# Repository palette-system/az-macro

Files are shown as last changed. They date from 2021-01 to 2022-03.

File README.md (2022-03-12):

# AZ-Macro

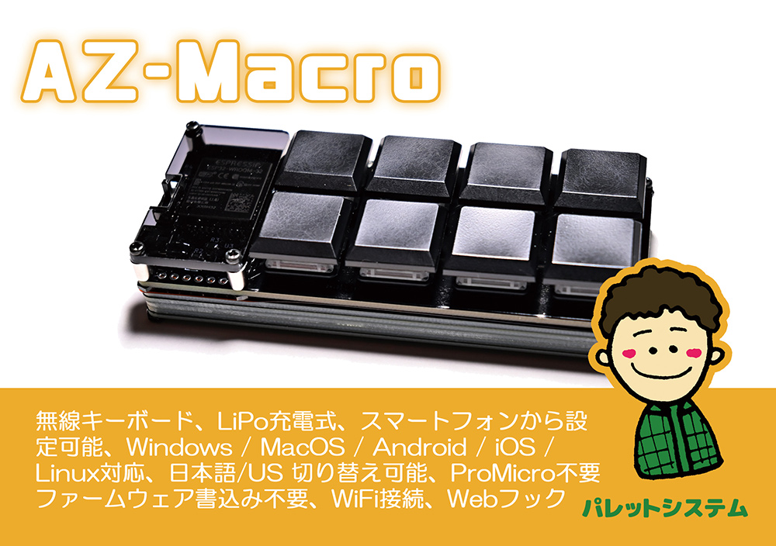
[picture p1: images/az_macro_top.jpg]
ボード設定


## メディア
<br>
【twitter】 山本アヒル 先生<br>
ツイッターPR<br>
https://twitter.com/AHIRU_7/status/1379755170599346183
<br><br>

<br>
【動画】Daihuku Keyboard 様<br>
組み立て、ZOOM、お絵かきソフト、google apps scriptとの連携<br>
https://www.youtube.com/watch?v=hTy6ZXIW0Vs
<br><br>

【動画＆ブログ】さきチャンネル 様<br>
組み立て、ショートカット設定、おみくじ、IFTTTとの連携<br>
動画： https://www.youtube.com/watch?v=Y7fYM1RlOd8&t=23s
<br>
ブログ： https://sakiot.com/iot-keyboard-az-macro/
<br><br>

【記事】AKIBA PC Hotline 様<br>
https://akiba-pc.watch.impress.co.jp/docs/news/news/1336355.html
<br>
https://akiba-pc.watch.impress.co.jp/docs/news/news/1306228.html
<br>

【記事】Yahooニュース 様<br>
https://news.yahoo.co.jp/articles/7b6afe8f1dbb792dc17484e3a8a71e1b7dceda1f
<br><br>

【ブログ】オノフ 様<br>
組み立て、設定方法<br>
https://onofuu.com/post-122/
<br><br>

【ブログ】道具眼日誌 様<br>
パーツ選び、組み立て、設定方法<br>
https://do-gugan.com/~furuta/archives/2021/05/az-macro_1.html
<br>
トラックボールの組み立て、設定方法<br>
https://do-gugan.com/~furuta/archives/2021/07/az-macro_trackball.html
<br><br>

【ツイート　イラスト】かわなえ 様<br>
https://twitter.com/kawai_nae/status/1494585308452585475
<br><br>

## ドキュメント
  
  ※キット購入の方も、組み立て済みの方もまずは「ファームウェアの初期セットアップ」を行って下さい。
  
[ファームウェアの初期セットアップ](/docs/firmware_write/)  
<br><br>

- [基本操作マニュアル](/docs/use_manual/)
- [作成マニュアル](/docs/az-macro-create-manual.pdf)
- [設定マニュアル](/docs/az-macro-setting-manual.pdf)
- [WEBHookマニュアル](/docs/webhook/)
- [ファームウェアの更新手順](/docs/firmware_update/)
- [入力できるキーの一覧](/docs/key_list/)
- [トラックボールユニットの設定](/docs/track_unit/)
<br><br>

## ファームウェア

- [ソース](/firmware/)
- [binファイル](/firmware/bin/azmacro/)
<br><br>

## ハードウェアデータ

- [プレートデータ](/plate/)
<br><br>

## リンク

- [パレットシステム通販サイト](https://palette-system.booth.pm/)

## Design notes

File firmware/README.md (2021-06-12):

# AZ-Macro ファームウェア
AZ-Macroで使用しているファームウェアソースです。<br>
こちらのソースは個人で利用する場合には自由にご利用いただいて大丈夫です。<br>
二次配布については非営利であれば著作権表示をして頂ければご利用して頂いて大丈夫です。<br>

<br><br>

ライセンス：　CC BY-NC-SA 4.0

<br><br>

## 対応商品

- AZ-Macro
- AZ-Macro (option)踏みキー

## 開発環境

- Arduino 1.8.13
- esp32 1.0.4
- ESP OTA 0.0.3
- NimBLE-Arduino 1.0.2
- ArduinoJson 6.17.2

## 書込み時のボード設定

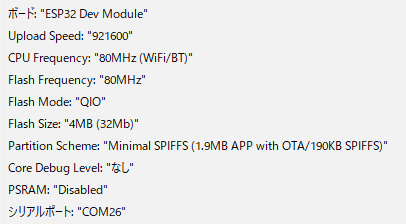
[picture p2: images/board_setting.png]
ボード設定


## AZ-66JP で SPIFFS 領域を16MBにする

[16MBフラッシュのESP32-WROVERでSPIFFSを最大限使えるようにする設定方法](https://kohacraft.com/archives/202012051149.html)

## こちらのツールを使用させて頂いています

- [PROGMEM作蔵さん](https://hello-world.blog.ss-blog.jp/2016-10-16)

## こちらのライブラリを使用させて頂いています

- [NimBLE-Arduino](https://github.com/h2zero/NimBLE-Arduino)
- [qrcode](https://github.com/ricmoo/qrcode/)

※ NimBLEはZIPファイルでライブラリ追加

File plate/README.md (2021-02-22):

# プレートデータ
AZ-Macroで使用している各プレートのDXFファイル、SVGファイルです。<br>
こちらのデータは個人で利用する分には自由にご利用いただいて大丈夫です。<br>
商用利用する場合も著作権表記して頂ければ自由にご利用いただいて大丈夫です。<br>

<br><br>

ライセンス：　CC BY-SA 4.0

<br><br>

## 保護プレート
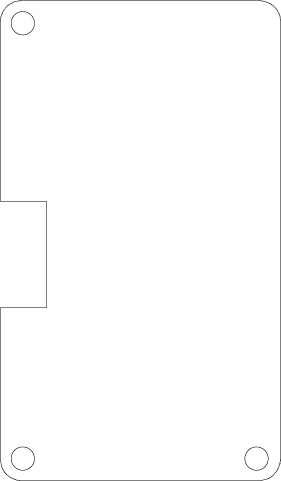
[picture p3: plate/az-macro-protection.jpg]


### Download
- [SVG](/plate/az-macro-protection.svg)
- [DXF](/plate/az-macro-protection.dxf)

<br><br>

## ミドルプレート
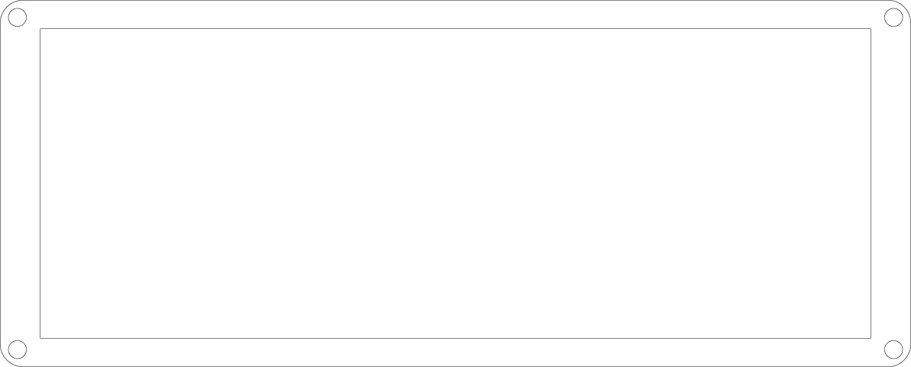
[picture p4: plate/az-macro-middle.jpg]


### Download
- [SVG](/plate/az-macro-middle.svg)
- [DXF](/plate/az-macro-middle.dxf)

<br><br>

## ボトムプレート
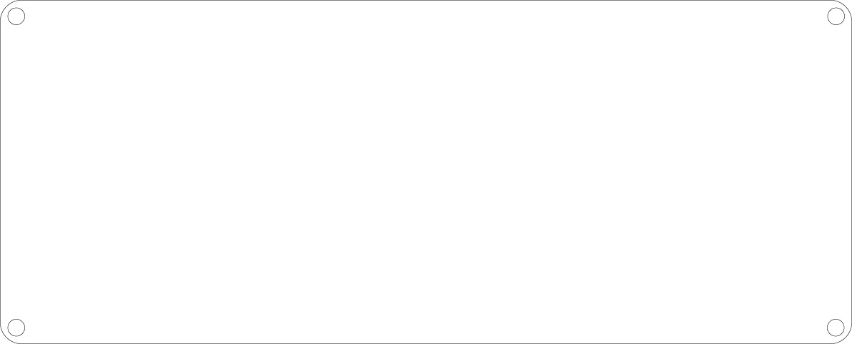
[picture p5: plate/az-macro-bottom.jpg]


### Download
- [SVG](/plate/az-macro-bottom.svg)
- [DXF](/plate/az-macro-bottom.dxf)

<br><br>

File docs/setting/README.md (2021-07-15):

# 設定方法

<br>

## 設定画面の入り方

[AZ-66JP](/docs/setting/az66jp/)

<br><br>

## マニュアル

[設定マニュアル(PDF)](/docs/az-macro-setting-manual.pdf)

<br><br>

## キーの設定

[暗記ボタンの設定](/docs/setting/key/ankey/)

[打鍵ボタンの設定](/docs/setting/key/daken/)

[カラーLEDボタンの設定](/docs/setting/key/led/)

<br><br>

## ユニットの設定

[液晶ユニットの設定](/docs/setting/unit/tft/)

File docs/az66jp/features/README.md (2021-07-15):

# AZ-66JP 製品特徴

<br>
<br>

## ■ 暗記ボタン機能
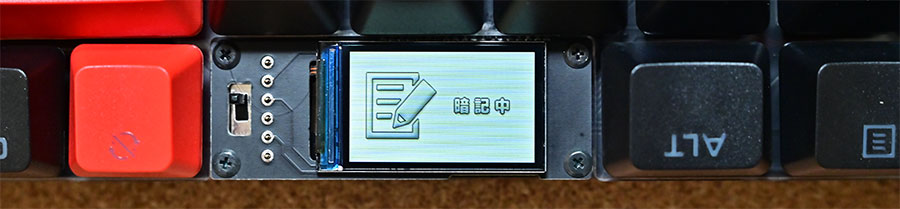
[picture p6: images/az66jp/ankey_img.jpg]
ankey_img
<br>
キーの推した順番、離した順番を暗記してボタンに覚えさせる機能を付けました。<br>
同じ入力を繰り返し入力したい場合、使用頻度が多ければ今までツールやショートカットキーを登録すれば実現できたのですが、使用頻度が少ない物は登録するのがいちいち面倒くさい場合が多くそのまま繰り返し入力している事が多かったのでこの機能を作りました。<br>
「暗記ボタン」を使う事でツールで設定をせず、今欲しいショートカットをスグに作る事ができます。<br>
使い方としては「暗記ボタン」として登録してあるキーを長押しするとキーボードが暗記モードになります。暗記モード中に入力したキー情報(暗記モード中も普通にキー入力されます)を最大1000回までキーを押した、離したの情報を暗記できます。<br>
暗記させたいキー入力が終わったらもう一度「暗記ボタン」を押すと暗記終了になります。暗記データがある状態で「暗記ボタン」を押すと暗記してある入力が自動で入力されます。<br>
「暗記ボタン」はキーマップの設定からいくつも登録できてESP32の容量が許す限り登録可能です。<br>
暗記したデータはESP32内に保存しますので、キーボードを再起動しても暗記した内容は保持されます。<br>
<br>
　※ 暗記するのはどのキーを押したかという情報なので、該当のキーのキーマップを書き換えると入力される内容も変わります<br>
　※ CtrlやAlt、カーソルキーやエンターキーTabキーなど登録できる全てのキーの暗記が可能です。<br>
　※ 「Ctrl＋C」→「Ctrl＋V」→「Ctrl＋V」→「Ctrl＋V」を暗記して選択したテキストを複数回張り付けるなども可能です<br>
<br>
暗記ボタンの使い方はこちら ： [リンク](/docs/az66jp/ankey/)

<br>
<br>

## ■ 打鍵ヒートマップ機能
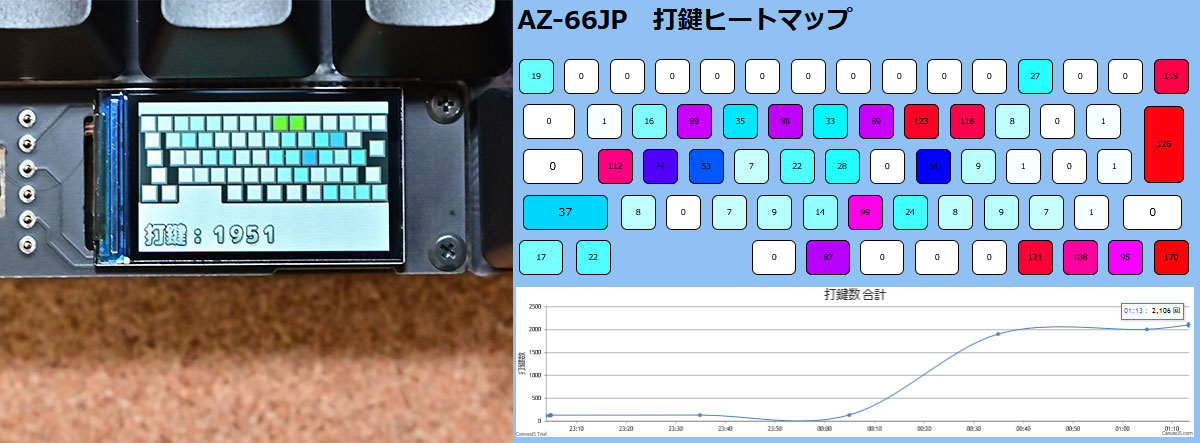
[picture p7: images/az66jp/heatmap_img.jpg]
heatmap_img
<br>
キーボードを起動してから現在までのトータル打鍵数とキーごとの打鍵数を30分おきにデータを残す事で、今どれくらいのペースでキーボードを入力したかを分かるようにしました。<br>
打鍵数は本体の液晶で確認できるだけでなく、液晶に表示されたQRコードを読み込めばスマホやPCからも打鍵ヒートマップを見れます。<br>
今の所は起動してからどれくらい打鍵したかしか見れませんが、ESP32本体に過去の打鍵数を保存できる容量はあるので今後のファームウェアアップデートで過去の分もさかのぼって確認できるようにする予定です。<br>

<br>
<br>

## ■ アプリのインストール無し、専門知識無しにキーマップを変更できる
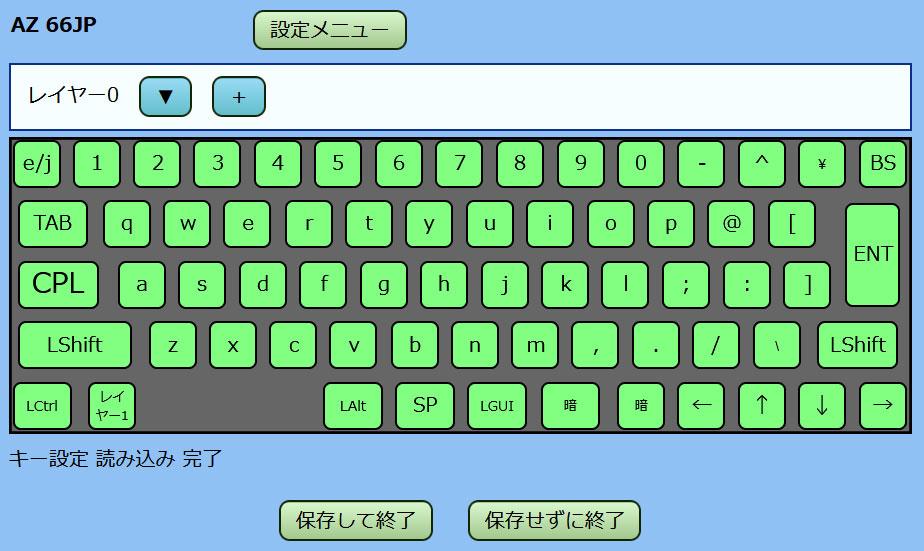
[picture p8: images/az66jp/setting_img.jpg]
setting_img
<br>
AZ-Macro同様のファームウェアを採用し、スマホやPCからWifiに接続するだけで設定画面が開けます。<br>
専門知識が無くても設定画面を見ればすぐに操作できるようになっていて、自作キーボードを初めて触る方でも簡単にキーマップの編集が行えます。<br>
レイヤー機能も搭載していて、Fnボタンのように押したまま他のボタンを押した時の動作を登録できます。レイヤー数に制限は無く複数のレイヤーが作成可能です。<br>

<br>
<br>

## ■ 初めての人も使いやすい日本語配列
66キーの60％サイズなので十字キーが横並びになっていたりスペースキーを狭くしていますが、普段使っているキーボードに近い日本語配列を採用しました。<br>
デフォルトのキーマップでは左下のCtrlの隣がレイヤー切り替えボタンとなっていて、そのボタンを押したまま最上列のキーを押すとF1～F12のファンクションキーも押せます。<br>
全てのキーに割り当てられるキーは設定ページから好きなように変更できます。<br>

<br>
<br>

## ■ 対応OS
WindowsやMacでの使用はもちろんの事、Android、iPhone、iPadなどのモバイル端末との接続もできるようになっています。<br>
特にiOSへ問題なく接続できる製品は少ないようでライブラリの修正が大変でしたが問題なく接続できるようになっています。<br>
また日本語キーボード←→USキーボードの変更も設定画面から変更できるようになっているので、PCやスマホの設定に合わせて変更して下さい。<br>

<br>
<br>

## ■ 打鍵音、打鍵感
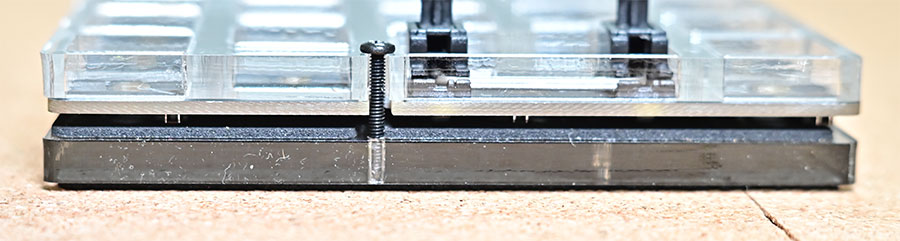
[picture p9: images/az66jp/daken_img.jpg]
daken_img
<br>
打鍵音はメカニカルスイッチを使用する上で重要な要素と考えており音についてはかなりこだわりました。<br>
打鍵時のPCBのカチャカチャ音を失くすためトッププレートは隙間の少ない専用の5mmアクリルプレートを採用。<br>
構造はトッププレートとボトムプレートを支柱でとめるのが主流ですが、そうするとボトムプレートに振動が伝わりボトムプレートがカチャカチャ鳴ってしまうので、あえて繋げず間に滑り止め用のスポンジでPCBとトッププレートを支える構造にしました。<br>
スポンジが振動を吸収してくれるので長時間の作業での指への負担を軽減してくれるのと、スポンジ内に空気が入っているため静音材の役割も果たしてくれて余計な音が鳴るのをを減らしてくれます。<br>
キーボードの裏にもこだわり、ゴム足を使用せず裏にもスポンジを採用しました。<br>
ゴム足を付けると机とボトムプレートの間に空いた空間のせいでボトムプレートから響き音が出てしまうので、点ではなく面でキーボードを支える事で余計な音が鳴るのを減らしてくれます。<br>
打鍵音には好みがあるので一概に良し悪しを決める事はできないのですが、テスターでテストしている打鍵音に近い状態でキー入力できるようこだわりましたので是非試してみて下さい。<br>

<br>
<br>

## ■ ESP32
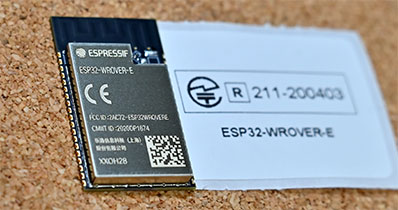
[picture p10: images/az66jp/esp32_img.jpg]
esp32_img
<br>
マイコンはESP32-WROVER-E(16MB)を採用しました。このマイコンは消費電力も大きいし、本体サイズも大きくPCBへの配置もしにくいため自作キーボードに向いていません。<br>
あえてESP32を採用したのは、現在キーボードで主流であるAVRマイコンに比べメモリも大きく多機能(Wifi、Bluetooth、タッチセンサ、DACなど)であるため今までのキーボードでは実装できなかったいろいろな機能が付ける事ができると考えました。<br>
AZ-66JPでは他のキーボードに無い機能をお届けいたします。<br>

<br>
<br>

## ■ カラー液晶
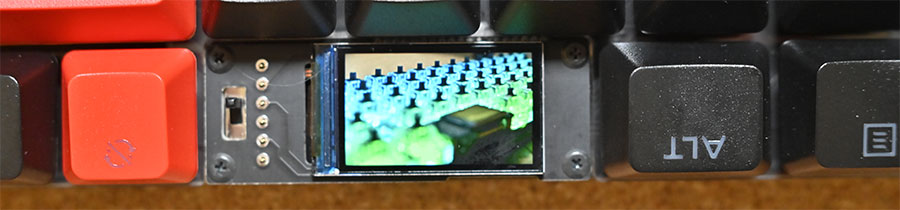
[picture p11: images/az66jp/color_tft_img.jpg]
<br>
キーボードに機能を追加していく上で操作情報を画面表示するために液晶が必須になり採用しました。<br>
ESP32の大容量があるのでカラーで画像表示をしたかったのと、空いたスペースに収まる最大のサイズにしたく240×135というサイズの液晶を採用しました。<br>
液晶の表示ライブラリが動作が遅い物が多く、表示を切り替えている間にキー入力がされるとキーが入力されない事があったので、ライブラリの通信部分の高速化や、画面の一部分だけの書換えで通信量を減らすなどしてキー入力に影響が出ないよう調整するのに苦労しました。<br>
部屋を暗くすると液晶が眩しくなってしまうため、液晶裏にボリュームを付けて液晶の明るさを調整できるようになっています。<br>
そのままボリュームを付けるとPCB外に飛び出た部分がGH60サイズのケースにあたってしまい入らなくなるので、PCBを少し凹ませてその部分でボリュームを調節できるようになっています。<br>
設定ページからJPEG、PNGの画像ファイルを設定すれば待ち受けの画像を変更できます。<br>

<br>
<br>

## ■ GH60のケース互換
GH60互換のケースは種類が多く沢山のデザインや素材があるため、初めて自作キーボードを手にする方が選びやすいケースだと思います。<br>
なのでPCBはGH60互換となるよう設計しました。アルミのケースも2種類ほど試しましたが問題なくBluetooth接続できました。<br>
ESP32の実装位置も、最初は裏面に設置していたのですがそうするとケースによってぶつかってしまう事があったのでGH60ケース互換にするためにESP32の実装は表面になっています。<br>
<br>
　※ 細かい所で差があったり表面実装しているパーツに干渉する可能性があるので互換ケースに入れる際は自己責任でお願いいたします<br>

<br>
<br>

## ■ 電源の接続
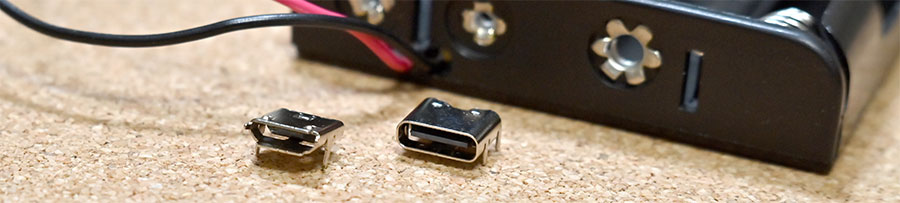
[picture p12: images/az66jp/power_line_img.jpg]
<br>
基本電源はモバイルバッテリーの利用を想定していますが、1種類のコネクタだけではなく選べるようにしました。<br>
コネクタをMicroB、Type-C、銅線から選ぶ事ができます。PCはもちろんUSB充電用のアダプタからUSBコネクタへの給電や、乾電池だと単３を３～４本で動作する事ができます。<br>
キットで購入するとコネクタははんだ付けされていない状態ですので、銅線をはんだ付けしてドーターボードから給電する事も可能です。<br>
またUSBコネクタから電源スイッチの間にスルーホールの穴があけてあり、知識のある方はここにリチウムバッテリーの充電モジュールなどを拡張したりの改造ができるようになっています。(ここの拡張に関しては自己責任でお願いいたします)<br>
<br>
　※ MicroBコネクタのモバイルバッテリーを変換コネクタを使用してType-Cに変換してから給電するとバッテリーを認識しない場合があります。その場合AZ-66JPの電源スイッチをONのままType-Cのコネクタをゆっくりさすと認識します。<br>
　※ 給電電圧は3.5～8Vの範囲内でお願いします。8V以上の電圧を流すとキーボードが壊れます。<br>
　※ 給電電流は500mAほど必要でCR2012などのボタン電池では電流が足りず起動しません。<br>

<br>
<br>

## ■ バッテリー内蔵ボトムプレート
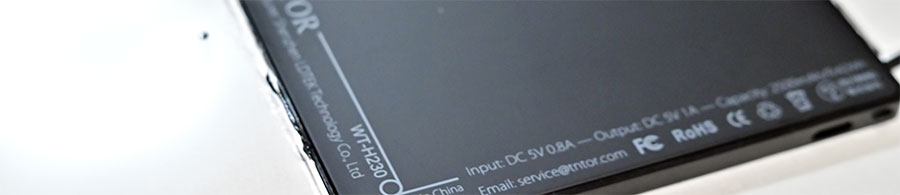
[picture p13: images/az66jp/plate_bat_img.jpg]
plate_bat_img
<br>
専用のバッテリー内蔵のプレートは必要だと思いオプションとして作成しました。<br>
まずシンプルで安全というのが最優先にあったのでバッテリーユニットはモバイルバッテリーを採用しました。<br>
次に可能な限り薄くしたかったのでモバイルバッテリーの中で薄くて手に入りやすい物を採用し、それに合うサイズのボトムプレートを作成しました。<br>
重みもあるのでキー入力時の安定感につながり完成度の高いプレートになりました。<br>
<br>
　※ PCBとの接続はMicroBコネクタでの接続をお願い致します。<br>

<br>
<br>

## ■ キースイッチのホットスワップ
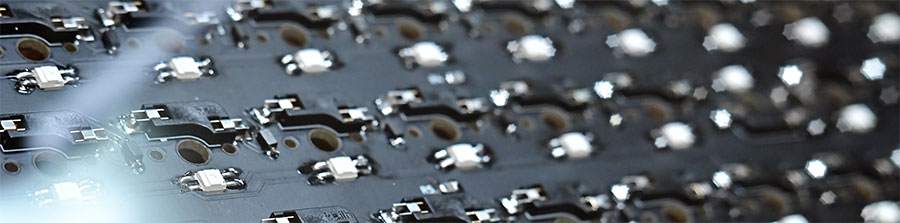
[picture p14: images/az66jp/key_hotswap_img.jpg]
key_hotswap_img
<br>
キースイッチはPCBへ直接はんだ付けではなくソケットを使用してキースイッチを抜き差しできるホットスワップを採用しました。<br>
打鍵ヒートマップ機能によりキーごとの使用頻度が可視化できるため、使用頻度を元にキーごとに重みの違うスイッチに変更したりチューニングができる仕様になっています。<br>
<br>
<br>

## ■ 全てのキーにカラーLED搭載
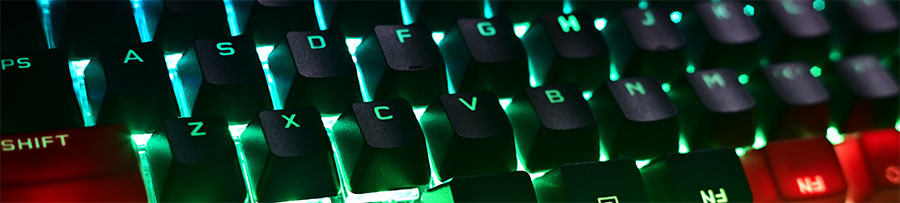
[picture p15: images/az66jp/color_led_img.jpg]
color_led_img
<br>
通常Bluetoothキーボードでは電池の消費が激しいのでカラーLEDは付けないのが主流なのですが、せっかくの自作キーボードなので全てのキーに対してカラーLEDを搭載しました。<br>
ライトのON/OFFや、明るさ調節、カラー設定などは変えたい時にぱっと変更できるよう「Fn ＋ Q」などのキーでキーボード上で設定が変更できる仕様になっています。<br>
<br>
　※ LEDをはんだ付けしなくてもキーボードとして機能しますので消費電力を抑えたい場合はLED無しでも組み立て可能です。<br>
<br>
<br>

## ■ WEBフック
AZ-Macro同様WEBフックを使えるようにしました。キースイッチが押されたのをトリガーにHTTPリクエストを送信できます。<br>
IFTTTと連携して家電の操作や、自前で用意したWEBAPIを実行する事ができます。<br>

<br>
<br>

## ■ マウス操作
AZ-Macro同様マウス操作も可能です。<br>
キーを押している間カーソルを上下左右へ移動したり、右クリック、左クリックなども登録可能です。<br>

<br>
<br>

## ■ 連打機能
AZ-Macro同様キーを押している間、指定したキーを連打する事ができます。<br>
連打の速度は細かく設定できるようになっています。<br>

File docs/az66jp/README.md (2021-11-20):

# 暗記キーボード (AZ-66JP)

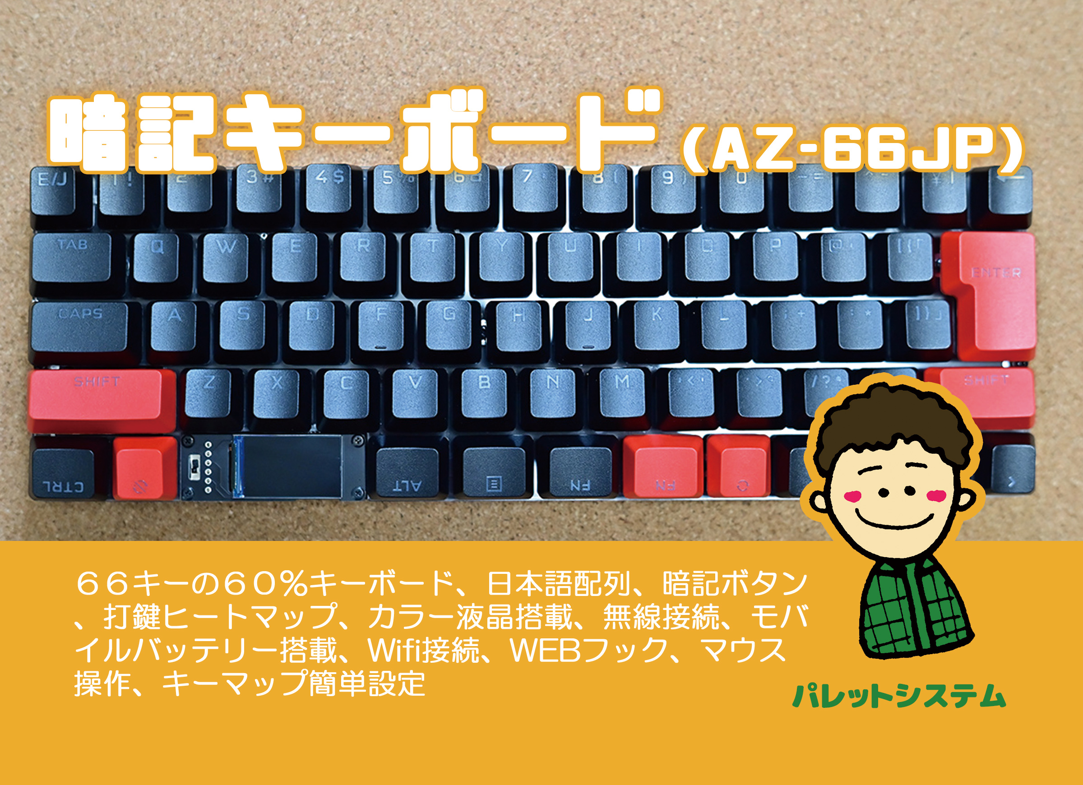
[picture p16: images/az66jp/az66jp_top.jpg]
AZ-66JP


[製品特徴](/docs/az66jp/features/)

[入っている物](/docs/az66jp/builtin_parts/)

[別途必要な物](/docs/az66jp/parts_prepare/)

[商品写真](/docs/az66jp/photos/)

<br>

## メディア

<br>
【動画】Daihuku Keyboard 様<br>
組み立て、操作説明、打鍵音<br>
https://www.youtube.com/watch?v=kJmM8BKnjaU
<br><br>

<br>
【動画】 ゲームギーク 様<br>
組み立て、操作説明、打鍵音<br>
https://www.youtube.com/watch?v=-eazsS1PuPM
<br><br>

<br>
【記事】 TALP キーボードブログ 様<br>
https://www.talpkeyboard.com/entry/2021/07/17/220259
<br><br>

<br>
【記事】 koktoh の雑記帳 様<br>
https://koktoh.hatenablog.com/entry/2021/08/11/175421
<br><br>

【記事】AKIBA PC Hotline 様<br>
https://akiba-pc.watch.impress.co.jp/docs/news/news/1341471.html
<br><br>

<br>
【動画】 ほぼ週刊キーボードニュース 様<br>
https://www.youtube.com/watch?v=489qCrel4ew
<br><br>

## ドキュメント

  ※キット購入の方も、組み立て済みの方もまずは「ファームウェアの初期セットアップ」を行って下さい。
  
[ファームウェアの初期セットアップ](/docs/az66jp/firmware_write/)  
<br><br>

- [組み立て手順](/docs/az66jp/build_guide/)
- [設定画面の入り方](/docs/setting/az66jp/README.md)
- [設定マニュアル](/docs/setting/README.md)

<br>

- [暗記ボタンの使い方](/docs/az66jp/ankey/)
- [打鍵ヒートマップの使い方](/docs/az66jp/heatmap/)
- [カラーLEDの設定方法](/docs/az66jp/rgbled/)
- [キー情報](/docs/az66jp/keydata/)

<br>

- [電源について](/docs/az66jp/power_line/)

<br>

## ファームウェア

- [ソース](/firmware/)
- [binファイル](/firmware/bin/az66jp/)
<br><br>

## ハードウェアデータ

## リンク

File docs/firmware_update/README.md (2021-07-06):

# ファームウェアのアップデート手順
AZ-Macroのファームウェアのアップデート手順の説明をします。  

## 対象のbinファイルのダウンロード
まずはアップデートするbinファイルをgithubからダウンロードします。  
下記リンクを開き対象のbinファイルをダウンロードして下さい。  

[ファームウェア リスト リンク](/firmware/bin/azmacro/)  

対象のファイルを選びます。  
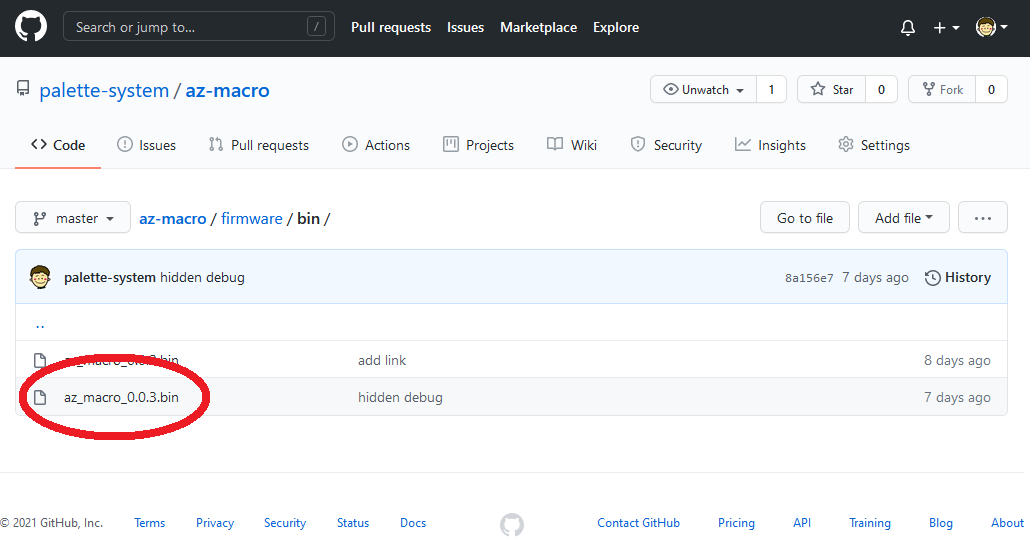
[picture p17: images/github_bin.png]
  

「Download」を押します。  
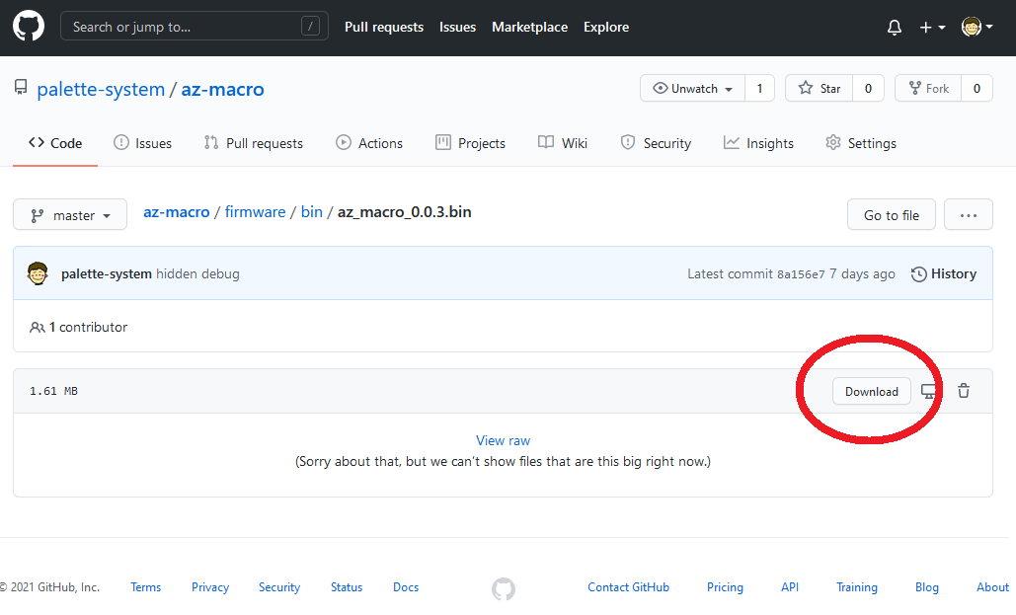
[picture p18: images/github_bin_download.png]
  

「ファイルを保存する」を選択して「OK」を押します。  
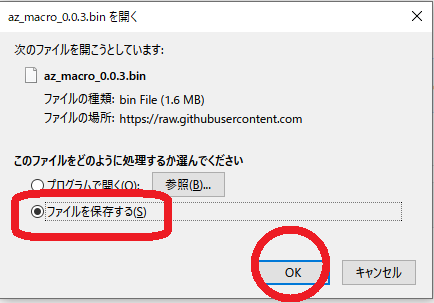
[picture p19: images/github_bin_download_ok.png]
  

## 設定画面からファームウェア更新

- AZ-Macroを設定モードで起動し、PCから設定画面を開きます  

- 「設定メニュー」から「ファームウェア」を押します  

- 先ほどダウンロードしたbinファイルを選択します  
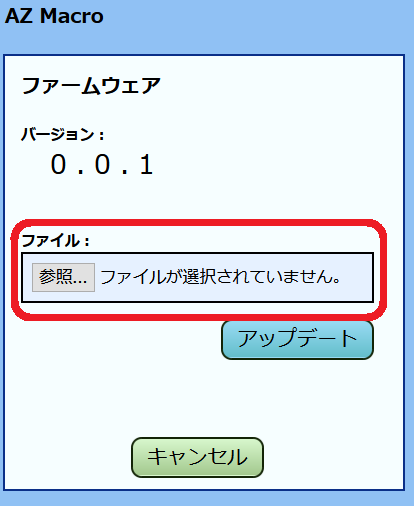
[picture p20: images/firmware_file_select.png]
  

- 「アップデート」を押します  
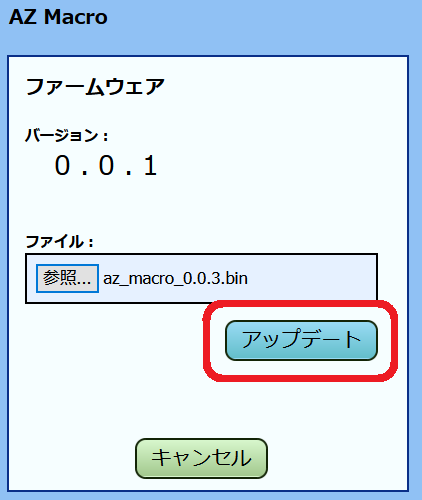
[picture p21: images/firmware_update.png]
アップデート
  

- binファイルがAZ-Macroに送られます  
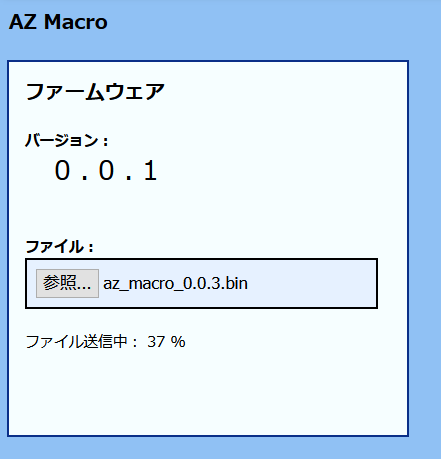
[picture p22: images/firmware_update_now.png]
ファイル送信中
  

- 送信が完了するとAZ-Macroがファームウェアの更新作業が始まります。(1分ほどかかりますのでそのままお待ち下さい)  
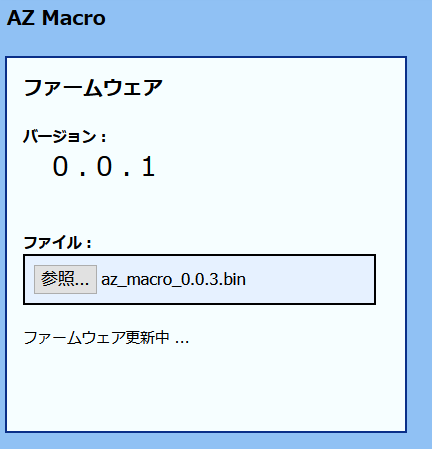
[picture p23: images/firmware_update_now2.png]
ファームウェア更新中
  

- 完了すると画面が切り替わりますのでページを閉じて下さい。  
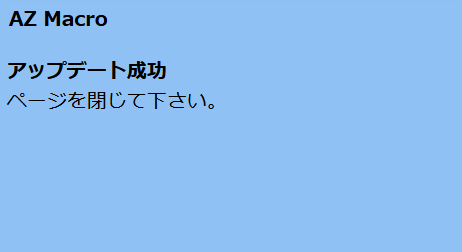
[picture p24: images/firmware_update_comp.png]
完了
  

## 注意点

ファームウェア更新後はプロファイルが書き換わっている事があるためペアリング設定を１度削除し、再度ペアリングしてからご使用ください。  
  
binファイルに不備があってファームウェアが更新できなかった場合でも「アップデート成功」のメッセージが出てしまいます。  
ファームウェアが更新されたかどうかは再度管理ページを開いてファームウェアのバージョンをご確認下さい。

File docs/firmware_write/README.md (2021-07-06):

# ファームウェアの初期セットアップ
AZ-Macroのファームウェアの初期セットアップ手順の説明をします。  
  <br><br>
  
## 対象のbinファイルのダウンロード
まずはアップデートするbinファイルをgithubからダウンロードします。  
下記リンクを開き最新のbinファイルをダウンロードして下さい。  
  <br><br>

[こちらからファームウェアをダウンロード](/firmware/bin/azmacro/)  
  <br><br><br>

最新のファイルを選びます。  
ファイルの選択  

「Download」を押します。  
ファイルの選択  

「ファイルを保存する」を選択して「OK」を押します。  
ファイルの選択  

## AZ-Macroにバッテリーを繋ぎ電源をONにする
まずバッテリーのPHプラグを出っ張りがある方を上にしてPCBボードへ接続して下さい。<br><br>
プラグは硬めなので強く差し込んで下さい。写真の所まで差し込めたらOKです。<br><br>

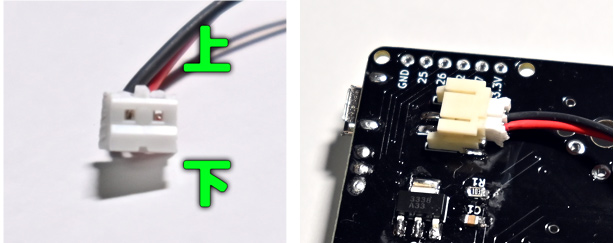
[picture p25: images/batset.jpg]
  
<br><br>

バッテリーが接続できると表面にあるスイッチを下に下げれば電源が入ります。<br><br>
電源が入ると緑色の電源LEDが点滅します。<br><br>

ファイルの選択  
<br><br>

## 設定画面からファームウェア書込み

- AZ-Macroの緑色のLEDが点滅してWiFiのアクセスポイントとなっているので、PCからAZ-MacroのWiFiへ接続します。

- 接続できるとファームウェア書込み画面が表示されます。  
ファイルの選択  

- ダウンロードしたbinファイルを選択します  
ファイルの選択  

- 「書込み」を押します  

- binファイルがAZ-Macroに送られます  
ファイル送信中  

- 送信が完了するとAZ-Macroがファームウェア書込み作業が始まります。(1分ほどかかりますのでそのままお待ち下さい)  
ファームウェア更新中  

- 完了すると画面が切り替わりますのでページを閉じて下さい。  
完了  

- 以上でファームウェアの初期セットアップ完了です。

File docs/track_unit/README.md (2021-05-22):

# AZ-Macro用 トラックボールユニット

トラックボールユニット

AZ-Macroにトラックボールを追加するユニットです。<br>

※ トラックボールモジュールは含まれませんので別途ご用意ください。

遊舎工房様のトラックボールモジュール販売ページ
https://shop.yushakobo.jp/collections/keyboard-parts/products/adtb7m

## 作成例

<br>

踏みキー接続ユニット<br><br>
踏みキー接続ユニット<br><br>
踏みキー接続ユニット<br><br>

## 設定方法

<br>
「設定メニュー」→「ユニット設定」→「変更」から「トラックボール」を選択して下さい。<br>

設定方法１<br><br>

「決定」を押すとAZ-Macroが再起動しますので、もう一度設定画面を開きなおすとトラックボールユニット用の設定が増えます。<br>
設定方法２<br><br>

※ AZ-Macroを通常起動してトラックボールを触るとマウスカーソルが移動するようになっています。<br><br>

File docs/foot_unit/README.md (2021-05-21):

# AZ-Macro用 踏みキー接続ユニット

踏みキー接続ユニット

AZ-Macroに踏みキーを接続するためのユニットです。<br>
オーディオ商品の「サステインペダル」をキースイッチとして使用する事ができます。<br>
設定は他のキー同様設定ページからショートカットキーやWEBフックを割り当てられます。<br>

## 作成例

<br>

踏みキー接続ユニット<br><br>

## 設定方法

<br>
「設定メニュー」→「ユニット設定」→「変更」から「踏みキー」を選択して下さい。<br>

設定方法１<br><br>

「決定」を押すとAZ-Macroが再起動しますので、もう一度設定画面を開きなおすと踏みキー用の設定が増えます。<br>
設定方法２<br><br>

※ 使用するサスティンペダルによって「踏んでいる間ONになる」「踏んでいる間OFFになる」の２パターンがありまして、接続した後キーが押しっぱなしになってしまう場合は設定画面にある「入力反転」を「する」に変更して試してみて下さい。<br><br>

## 動作確認済みサスティンペダル

YAMAHA ( ヤマハ ) / FC5　フットスイッチ <br>
https://www.soundhouse.co.jp/products/detail/item/82965/

<br>

BEHRINGER ( ベリンガー ) / FS112BX<br>
https://www.soundhouse.co.jp/products/detail/item/204811/

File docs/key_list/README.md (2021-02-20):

# 入力できるキーのリスト

|  No  |  Key  |
| ---: | :--- |
|  1  |  Left Ctrl  |
|  2  |  Left Shift  |
|  3  |  Left Alt  |
|  4  |  Left GUI  |
|  5  |  Right Ctrl  |
|  6  |  Right Shift  |
|  7  |  Right Alt  |
|  8  |  Right GUI  |
|  9  |  ↑  |
|  10  |  ↓  |
|  11  |  ←  |
|  12  |  →  |
|  13  |  BackSpace  |
|  14  |  Tab  |
|  15  |  Enter  |
|  16  |  Esc  |
|  17  |  Insert  |
|  18  |  Home  |
|  19  |  Delete  |
|  20  |  End  |
|  21  |  CapsLock  |
|  22  |  PrtScreen  |
|  23  |  ScrollLock  |
|  24  |  Pause  |
|  25  |  PageUp  |
|  26  |  PageDown  |
|  27  |  ひらがな カタカナ  |
|  28  |  Eject  |
|  29  |  Media Next  |
|  30  |  Media Previous  |
|  31  |  Media Stop  |
|  32  |  Media Play / Pause  |
|  33  |  Media Mute  |
|  34  |  Media Volume +  |
|  35  |  Media Volume -  |
|  36  |  変換  |
|  37  |  無変換  |
|  38  |  Kana(mac)  |
|  39  |  英数(mac)  |
|  40  |  App  |
|  41  |  Power  |
|  42  |  F1  |
|  43  |  F2  |
|  44  |  F3  |
|  45  |  F4  |
|  46  |  F5  |
|  47  |  F6  |
|  48  |  F7  |
|  49  |  F8  |
|  50  |  F9  |
|  51  |  F10  |
|  52  |  F11  |
|  53  |  F12  |
|  54  |  スペース  |
|  55  |  !  |
|  56  |  *  |
|  57  |  #  |
|  58  |  $  |
|  59  |  %  |
|  60  |  '  |
|  61  |  :  |
|  62  |  )  |
|  63  |  (  |
|  64  |  ~  |
|  65  |  `  |
|  66  |  ,  |
|  67  |  -  |
|  68  |  _  |
|  69  |  .  |
|  70  |  /  |
|  71  |  +  |
|  72  |  ;  |
|  73  |  <  |
|  74  |  ^  |
|  75  |  >  |
|  76  |  ?  |
|  77  |  "  |
|  78  |  @  |
|  79  |  ]  |
|  80  |  &#124;  |
|  81  |  [  |
|  82  |  {  |
|  83  |  }  |
|  84  |  &  |
|  85  |  =  |
|  86  |  \\  |
|  87  |  &yen;  |
|  88  |  半角/全角  |
|  89  |  0  |
|  90  |  1  |
|  91  |  2  |
|  92  |  3  |
|  93  |  4  |
|  94  |  5  |
|  95  |  6  |
|  96  |  7  |
|  97  |  8  |
|  98  |  9  |
|  99  |  a  |
|  100  |  b  |
|  101  |  c  |
|  102  |  d  |
|  103  |  e  |
|  104  |  f  |
|  105  |  g  |
|  106  |  h  |
|  107  | i |
|  108  | j |
|  109  | k |
|  110  | l |
|  111  | m |
|  112  | n |
|  113  | o |
|  114  | p |
|  115  | q |
|  116  | r |
|  117  | s |
|  118  | t |
|  119  | u |
|  120  | v |
|  121  | w |
|  122  | x |
|  123  | y |
|  124  | z |

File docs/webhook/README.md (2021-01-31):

# WEBHook 
WEBHookを使用する事でIFTTTと連携できるSNSやスマートリモコンを操作したり、サーバー上に置いた自分のプログラムを実行する事ができます。  
ここではAZ-MacroでWEBHookを使用する場合の注意事項やサンプルを紹介します。  
  
AZ-Macroでは http:// のURLも https:// のURLも指定できますが https:// の方では暗号化の処理に時間がかかってしまい、1～2秒ほどかかります。  
セキュリティの必要のない通信であれば http:// でのアクセスの方が処理が早いです。  

## AZ-Macro の WEBHookでできる事

- http、https でのリクエスト送信
- GET、POST でのリクエスト送信
- 独自のヘッダー追加
- GETパラメーター送信
- POSTパラメーター送信
- 取得した内容をキー入力する
- 取得したステータスコードをキー入力する

## AZ-Macro の WEBHookでできない事

- ftp:// などのHTTPプロトコル以外のリクエスト送信
- POSTパラメータにバイナリデータを含める
- キー入力させる時に全角文字があると正常に入力できない

## サンプル

- [押すたびに増えるカウンタ](/docs/webhook/sample/counter/)

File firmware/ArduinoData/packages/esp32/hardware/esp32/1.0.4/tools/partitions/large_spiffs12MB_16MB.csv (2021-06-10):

# Name | Type | SubType | Offset | Size | Flags
nvs | data | nvs | 0x9000 | 0x5000
otadata | data | ota | 0xe000 | 0x2000
app0 | app | ota_0 | 0x10000 | 0x200000
app1 | app | ota_1 | 0x210000 | 0x200000
spiffs | data | spiffs | 0x410000 | 0xBF0000

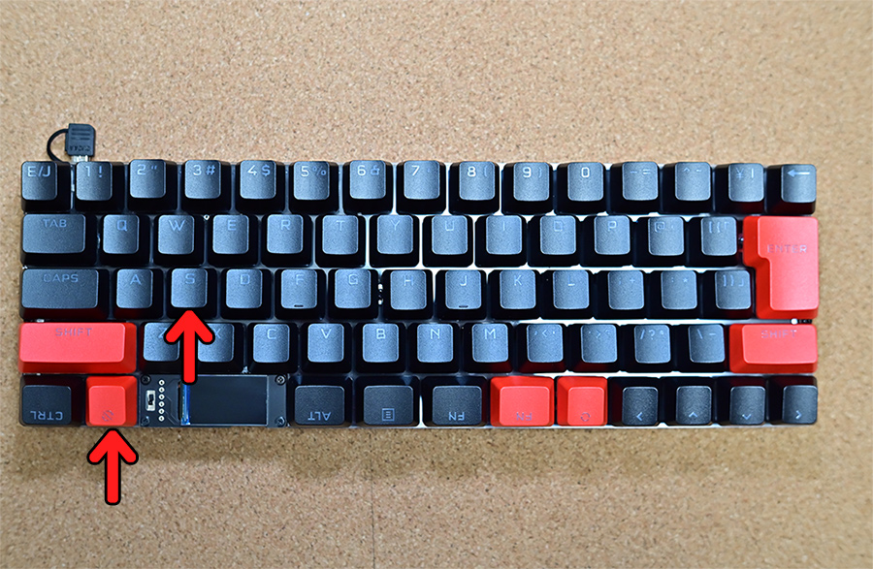
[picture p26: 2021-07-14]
images/az66jp/dakey_2.jpg

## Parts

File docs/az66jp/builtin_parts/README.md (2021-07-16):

# 入っている物
<br>

## PCB
<table>
  <tr>
    <th>写真</th>
    <th>パーツ名</th>
    <th>個数</th>
  </tr>
  <tr>
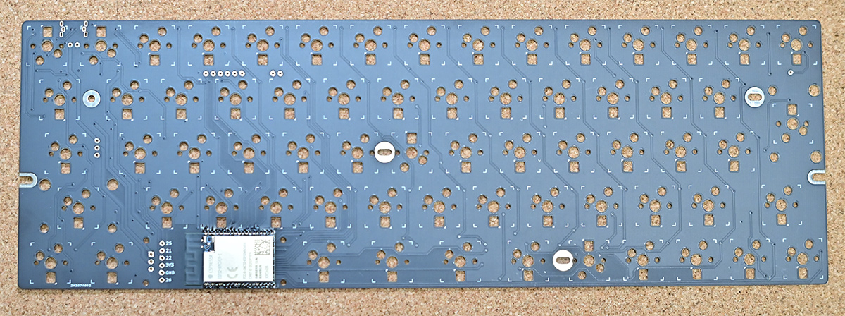
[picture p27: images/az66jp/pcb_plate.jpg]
    <td></td>
    <td>PCB プレート</td>
    <td valign="center">1</td>
  </tr>
  <tr>
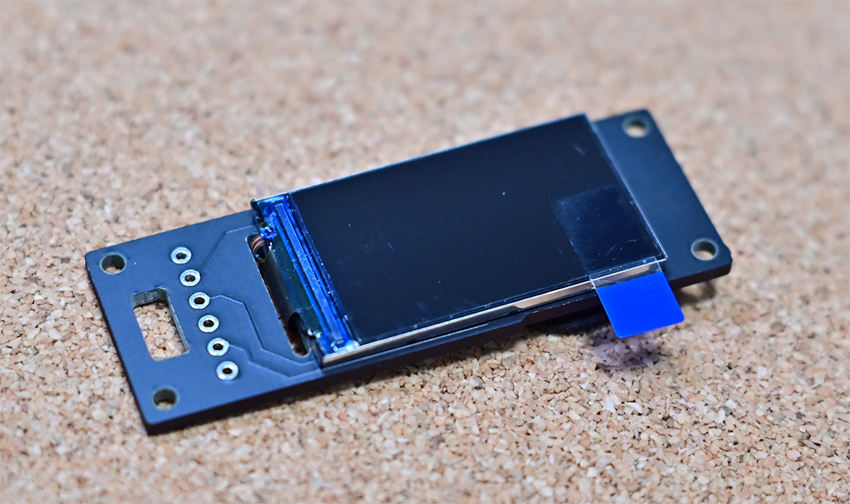
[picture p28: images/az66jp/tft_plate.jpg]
    <td></td>
    <td>カラー液晶プレート</td>
    <td valign="center">1</td>
  </tr>
  <tr>
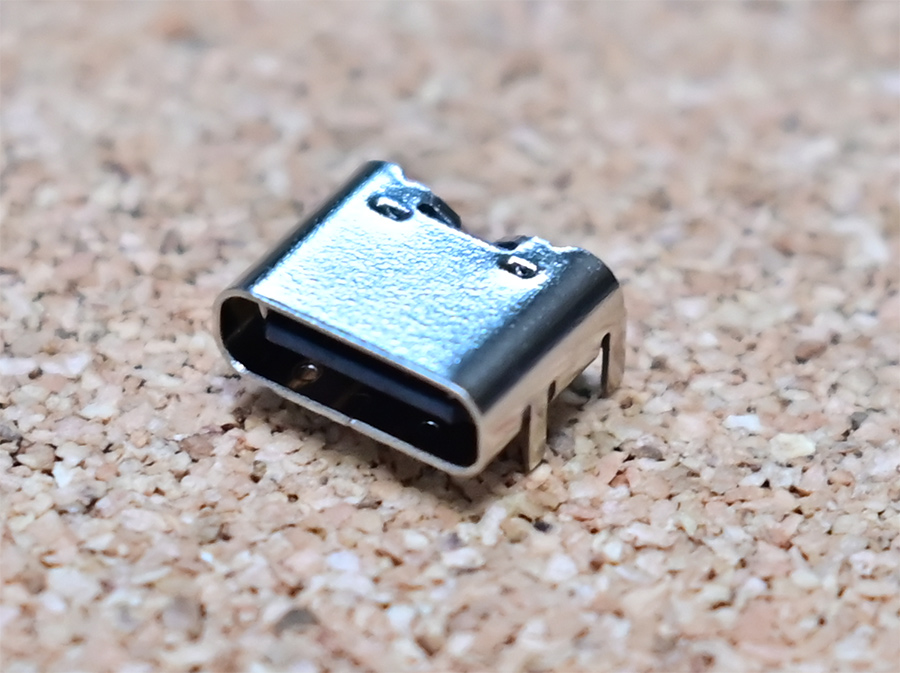
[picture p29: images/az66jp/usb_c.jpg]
    <td></td>
    <td>電源用USBコネクタ (Type-C)</td>
    <td valign="center">1</td>
  </tr>
  <tr>
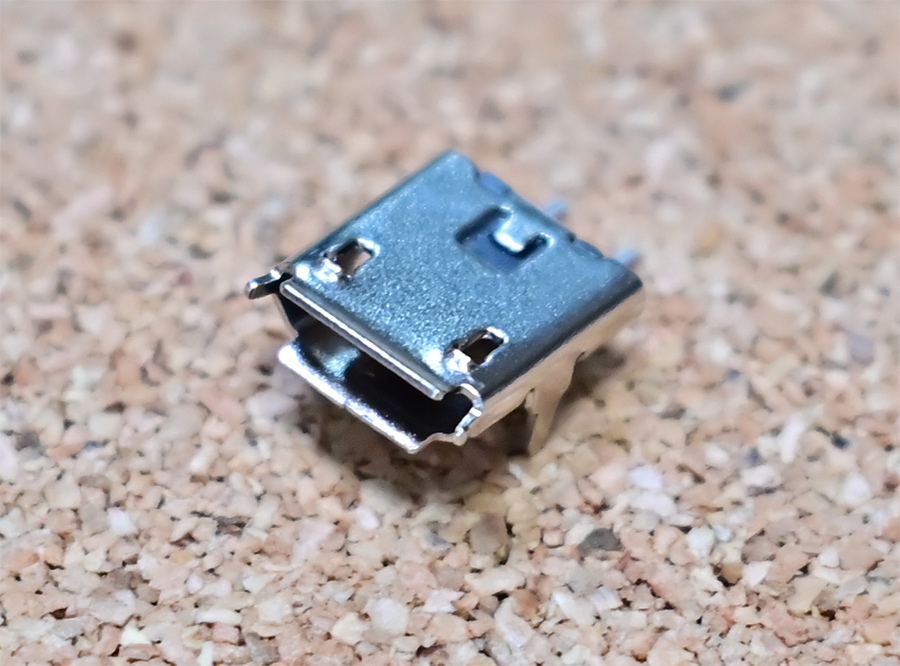
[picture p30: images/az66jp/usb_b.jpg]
    <td></td>
    <td>電源用USBコネクタ (MicroB)</td>
    <td valign="center">1</td>
  </tr>
  <tr>
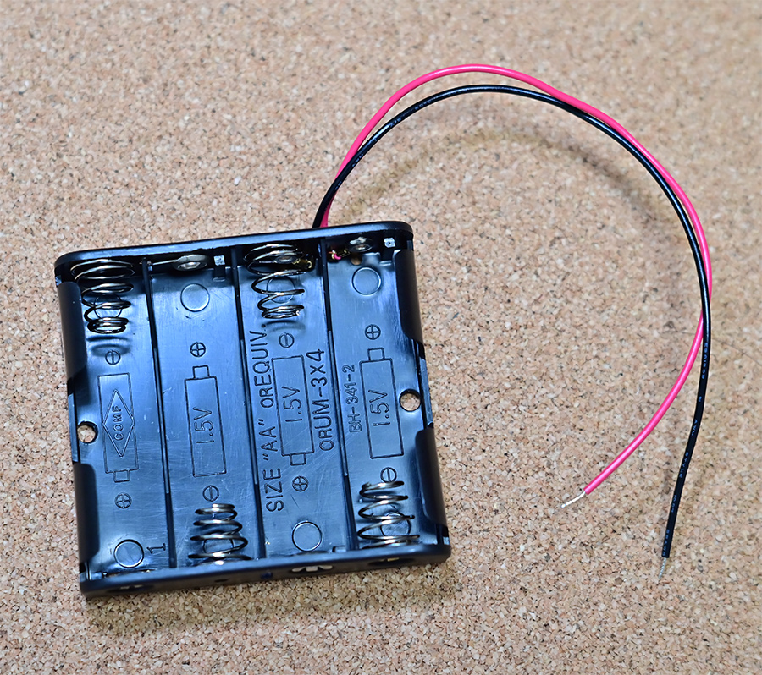
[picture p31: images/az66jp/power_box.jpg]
    <td></td>
    <td>電池ボックス (単3×4本)</td>
    <td valign="center">1</td>
  </tr>
  <tr>
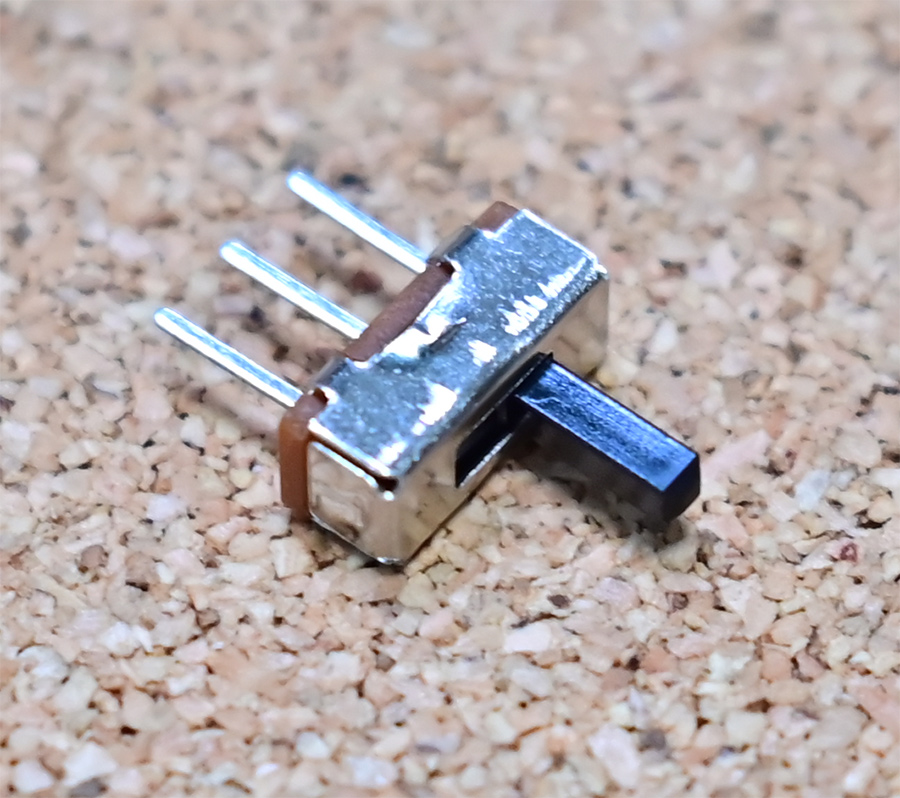
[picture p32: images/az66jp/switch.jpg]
    <td></td>
    <td>電源スイッチ</td>
    <td valign="center">1</td>
  </tr>
  <tr>
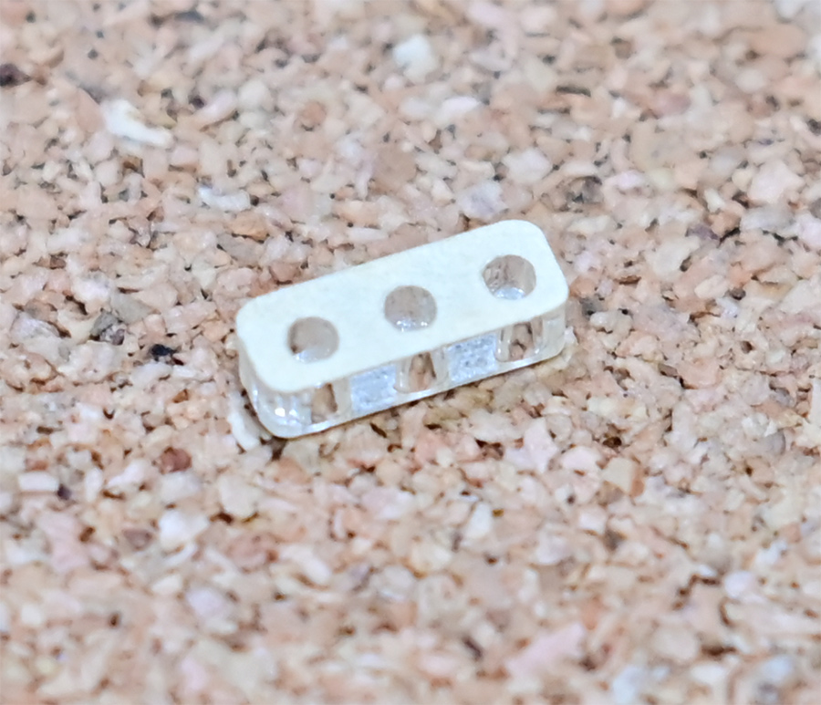
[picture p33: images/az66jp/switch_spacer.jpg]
    <td></td>
    <td>電源スイッチ用スペーサー</td>
    <td valign="center">1</td>
  </tr>
  <tr>
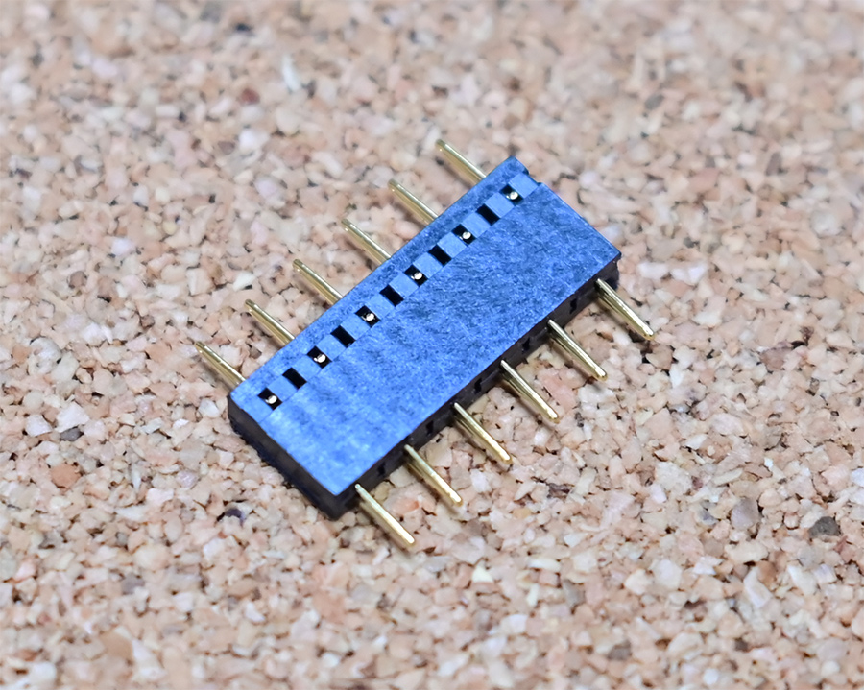
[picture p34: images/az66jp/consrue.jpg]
    <td></td>
    <td>液晶プレート接続用コンスル―(6pin 6mm)</td>
    <td valign="center">1</td>
  </tr>
  <tr>
    <td></td>
    <td>ジャンパー</td>
    <td valign="center">2</td>
  </tr>
  <tr>
    <td></td>
    <td>カラーLED(SK6812MINI-E)</td>
    <td valign="center">70</td>
  </tr>
  <tr>
    <td></td>
    <td>表面実装ダイオード(1N4148W)</td>
    <td valign="center">70</td>
  </tr>
  <tr>
    <td></td>
    <td>スイッチ用PCBソケット(CherryMX用)</td>
    <td valign="center">70</td>
  </tr>
  <tr>
    <td></td>
    <td>スペーサー (M2-6mm)</td>
    <td valign="center">4</td>
  </tr>
  <tr>
    <td></td>
    <td>スリムヘッドネジ (M2-3mm)</td>
    <td valign="center">10</td>
  </tr>
</table>

<br><br>

## プレートセット
<table>
  <tr>
    <th>写真</th>
    <th>パーツ名</th>
    <th>個数</th>
  </tr>
  <tr>
    <td></td>
    <td>トッププレート (5mm厚)<br><br>ボトムプレート (5mm厚)</td>
    <td valign="center">1</td>
  </tr>
  <tr>
    <td></td>
    <td>スポンジA <br>　(ボトムプレートの表用)<br><br>スポンジB <br>　(ボトムプレートの裏用)</td>
    <td valign="center">1</td>
  </tr>
  <tr>
    <td></td>
    <td>固定用ネジ (M2-14mm)</td>
    <td valign="center">8</td>
  </tr>
</table>

<br><br>

## バッテリー内蔵プレートセット
<table>
  <tr>
    <th>写真</th>
    <th>パーツ名</th>
    <th>個数</th>
  </tr>
  <tr>
    <td></td>
    <td>トッププレート (5mm厚)<br><br>ボトムプレート (5mm厚)</td>
    <td valign="center">1</td>
  </tr>
  <tr>
    <td></td>
    <td>スポンジA <br>　(ボトムプレートの表用)<br><br>スポンジB <br>　(ボトムプレートの裏用)</td>
    <td valign="center">1</td>
  </tr>
  <tr>
    <td></td>
    <td>固定用ネジ (M2-14mm)</td>
    <td valign="center">8</td>
  </tr>
  <tr>
    <td></td>
    <td>モバイルバッテリー<br> <a href="https://www.amazon.co.jp/gp/product/B083NMPH4L/" target="_blank">リンク</a></td>
    <td valign="center">1</td>
  </tr>
</table>

<br>
<br>

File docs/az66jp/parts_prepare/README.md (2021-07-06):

# キットに含まれない別途用意が必要な物
<br>

<table>
  <tr>
    <th>写真</th>
    <th>パーツ名</th>
    <th>個数</th>
  </tr>
  <tr>
    <td></td>
    <td>MXスイッチ スタビライザー (2Uサイズ)<br> <a href="https://shop.yushakobo.jp/collections/all-keyboard-parts/products/a0500st">リンク</a></td>
    <td valign="center">2</td>
  </tr>
  <tr>
    <td></td>
    <td>Cherry MX スイッチ<br>(互換品も可)<br> <a href="https://shop.yushakobo.jp/collections/all-switches/products/cherry-mx">リンク</a></td>
    <td valign="center">66</td>
  </tr>
  <tr>
    <td></td>
    <td>日本語配列キーキャップ<br> <a href="https://www.yodobashi.com/product/100000001006097828/">リンク</a></td>
    <td valign="center">1</td>
  </tr>
</table>

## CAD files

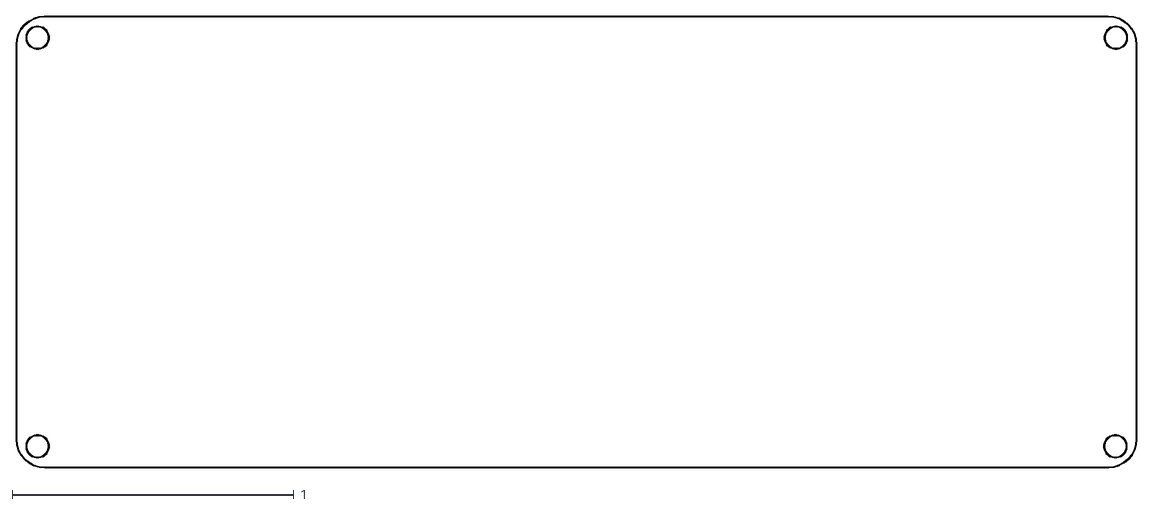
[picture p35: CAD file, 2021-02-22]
plate/az-macro-bottom.dxf
3.98 x 1.60

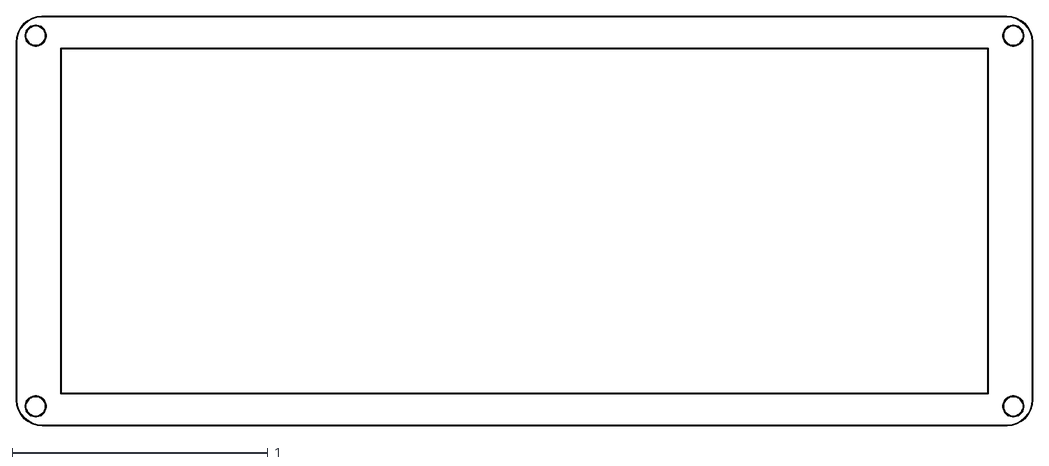
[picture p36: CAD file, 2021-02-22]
plate/az-macro-middle.dxf
3.98 x 1.60

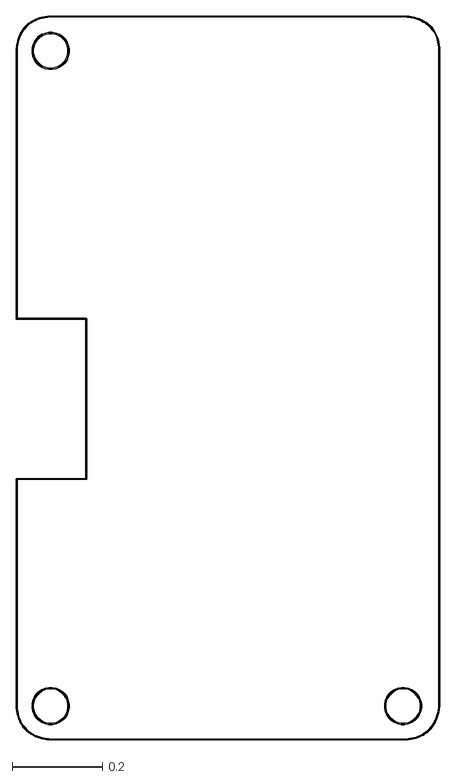
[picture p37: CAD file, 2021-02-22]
plate/az-macro-protection.dxf
0.937 x 1.60

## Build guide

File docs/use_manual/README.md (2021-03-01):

# 基本操作マニュアル
AZ-Macroの基本操作説明をします。
<br><br>
　※ ご利用には必ず最初にファームウェアの初期セットアップが必要です。<br>
 　　　マニュアルをを参考にファームウェアの初期セットアップを行って下さい。<br>
    　　[ファームウェアの初期セットアップマニュアル](/docs/firmware_write/)
<br>
<br><br>

## 本体説明
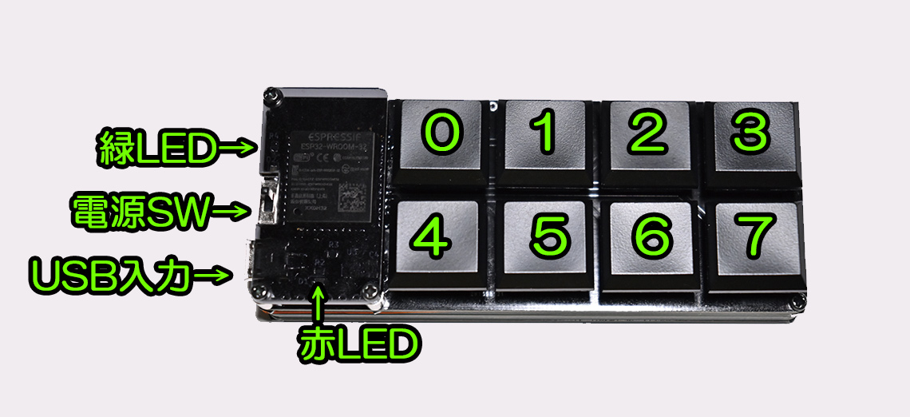
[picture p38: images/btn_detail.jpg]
本体説明
  

### 緑LED
|  状態  |  ステータス  |
|  --  |  --  |
|  消灯  |  電源OFF  |
|  点滅（ゆっくり）  |  設定モード、WIFIアクセスポイント  |
|  点滅（早い）  |  WEBフック中、ファームウェア書込み中  |
|  点滅（２回点灯）  |  WIFI接続中  |
|  点灯  |  電源ON  |

### 赤LED
|  状態  |  ステータス  |
|  --  |  --  |
|  消灯  |  充電無し、充電完了  |
|  点灯  |  充電中  |

※ 充電しながら電源ONにした場合、充電が完了しても赤LEDが点灯したままになります。

### 電源SW
|  状態  |  ステータス  |
|  --  |  --  |
|  上  |  電源OFF  |
|  下  |  電源ON  |

### USB入力
※ USBは充電用の電源入力のみです。接続している間リチウムバッテリーの充電が行われます。

### キースイッチ
各キーを押したまま電源をONにするとそれぞれ起動モードが変わります。
|  スイッチ  |  起動モード  |
|  --  |  --  |
|  ０キー  |  設定モードで起動  |
|  １キー  |  -  |
|  ２キー  |  -  |
|  ３キー  |  -  |
|  ４キー  |  レイヤー２をデフォルトにして起動  |
|  ５キー  |  レイヤー３をデフォルトにして起動  |
|  ６キー  |  レイヤー４をデフォルトにして起動  |
|  ７キー  |  レイヤー５をデフォルトにして起動  |

<br><br>

## 通常起動
通常起動中は緑LEDが点灯した状態で、PC、スマートフォンからBluetoothでキーボードとして認識できます。<br>
※ WIFI設定をしていると電源ONにした時に設定したWIFIに接続し、接続完了後Bluetoothキーボードとして認識するようになります。

<br><br>

## 設定モード起動
０キーを押したまま電源をONにすると設定モードとして起動し、緑LEDがゆっくり点滅した状態になります。<br>
設定モード中はWIFIのアクセスポイントとして動作していて、PC、スマートフォンからWIFI接続できます。<br>
設定モードの詳しい説明は設定マニュアルをご覧下さい。<br>
[設定マニュアル](/docs/az-macro-setting-manual.pdf)

<br><br>

## 拡張ポート
外部接続用の拡張ポートが付いています。<br>
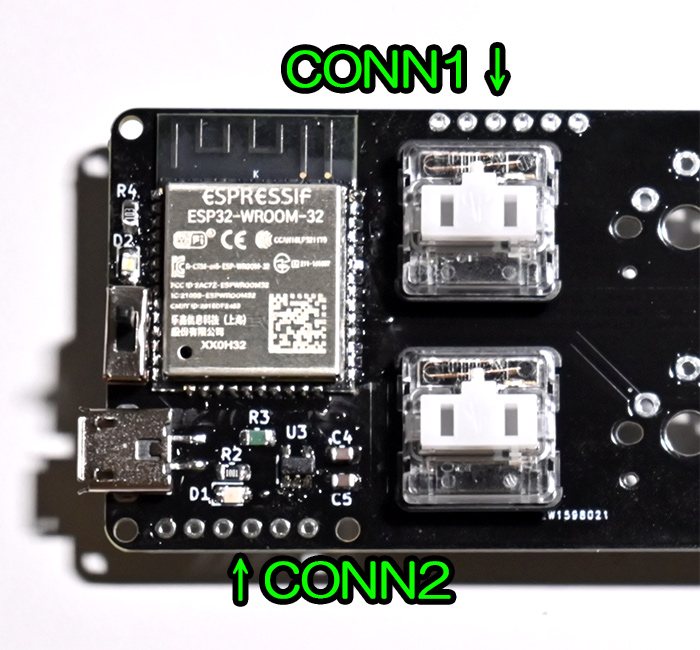
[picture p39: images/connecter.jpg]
拡張ポート
  

### CONN１
ESP32-WROOM-32 へ書き込みを行うポートです。<br>
スイッチサイエンスで購入できる「FLINT ESP Programmer」とピン配置が互換していてそのまま接続できます。<br>
またコンスル―対応のビアサイズになっているので、コンスル―を使用すれば本体へのはんだ付け無しに接続できます。<br>
[FLINT ESP Programmer](https://www.switch-science.com/catalog/5241/)

|  ピン  |  内容  |
|  --  |  --  |
|  １  |  EN  |
|  ２  |  TX  |
|  ３  |  RX  |
|  ４  |  VIN  |
|  ５  |  IO0  |
|  ６  |  GND  |

<br><br>

### CONN２
いろいろなセンサーやスピーカーなどの外部拡張ができるポートです。

|  ピン  |  内容  |
|  --  |  --  |
|  １  |  GND  |
|  ２  |  IO２５  |
|  ３  |  IO２６  |
|  ４  |  IO１２  |
|  ５  |  IO２７  |
|  ６  |  ３．３V OUT  |

<br><br>

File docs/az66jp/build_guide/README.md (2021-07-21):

# 組み立て手順

<br><br>

## 使う道具
<table>
  <tr>
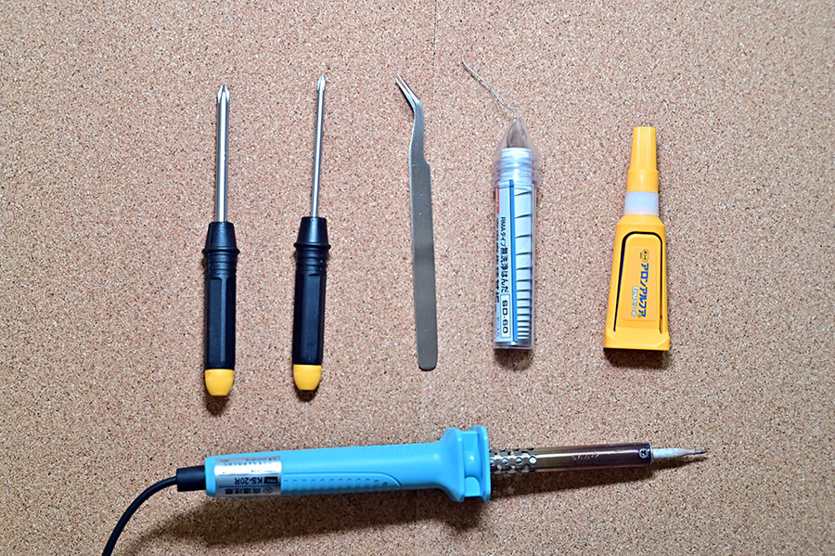
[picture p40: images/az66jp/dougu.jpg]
    <td></td>
    <td>
      プラスドライバー（小）<br>
      プラスドライバー（中）<br>
      ピンセット<br>
      はんだ<br>
      はんだごて<br>
      瞬間接着剤(バッテリー内蔵プレートで使用)
    </td>
  </tr>
</table>

<br><br>

## ダイオードのはんだ付け
<table>
  <tr>
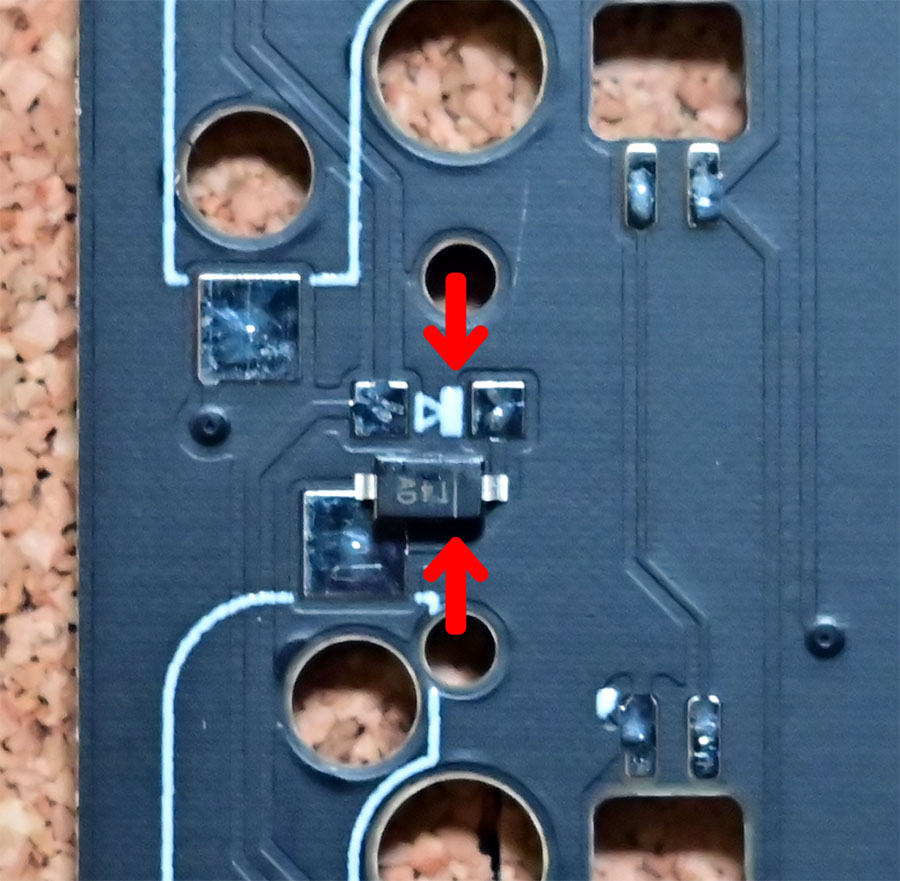
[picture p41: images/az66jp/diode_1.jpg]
    <td></td>
    <td valign="top">
      <b>向き合わせ</b><br>
      ダイオードの横線が入っている方の向きを合わせてはんだ付けして下さい。<br>
      向きを間違えるとスイッチが動作しないので注意して下さい。
    </td>
  </tr>
  <tr>
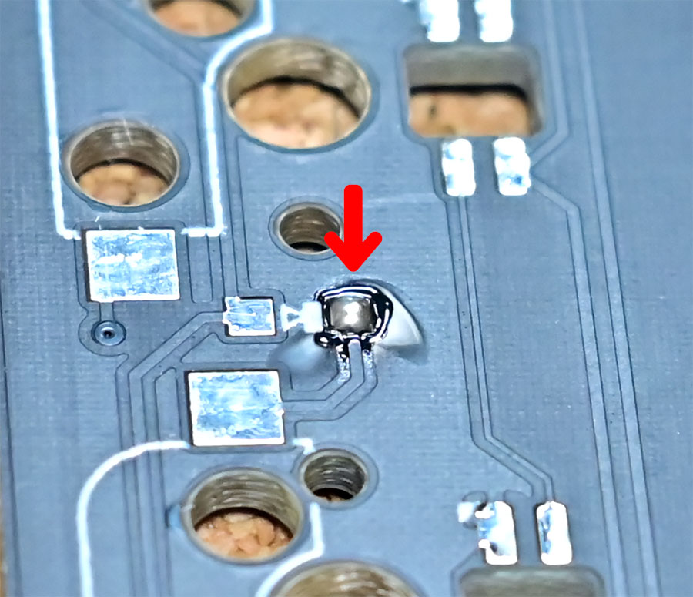
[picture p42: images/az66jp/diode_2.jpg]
    <td></td>
    <td valign="top">
      １．　まずPCB上の片側にはんだを乗せます。
    </td>
  </tr>
  <tr>
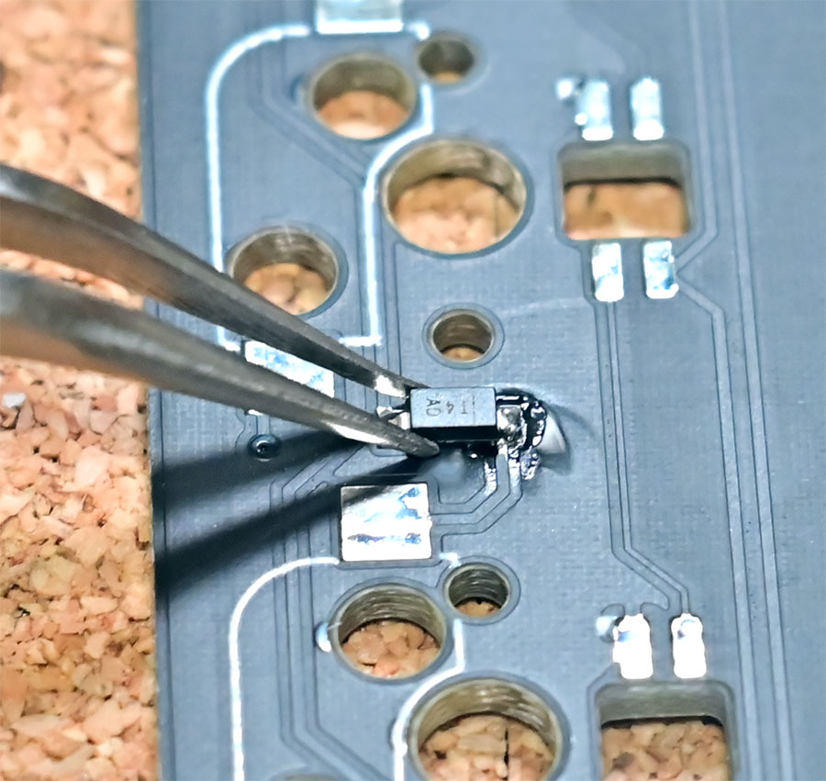
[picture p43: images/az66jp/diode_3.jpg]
    <td></td>
    <td valign="top">
      ２．　ピンセットでダイオードをつかみながら①で付けたはんだ部分にくっつけます。
    </td>
  </tr>
  <tr>
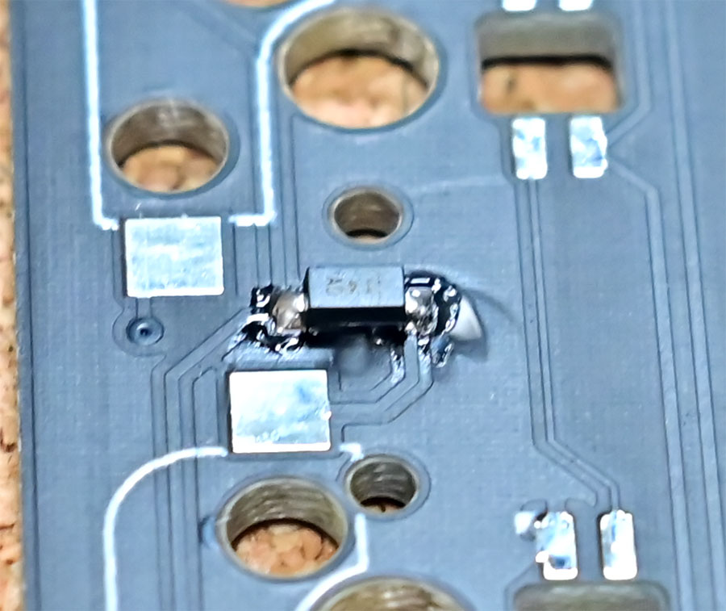
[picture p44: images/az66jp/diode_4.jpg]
    <td></td>
    <td valign="top">
      ３．　反対側もはんだ付けして完了です。<br>
      １．～３．を66個分繰り返します。
    </td>
  </tr>
</table>

<br><br>

## カラーLEDのはんだ付け
<table>
  <tr>
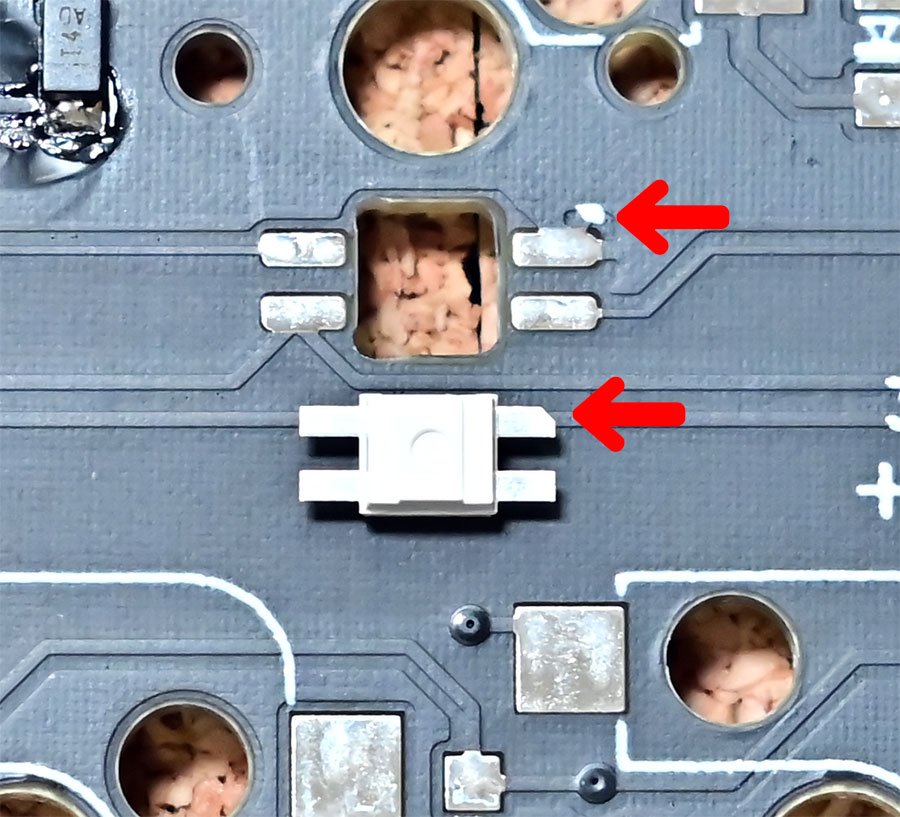
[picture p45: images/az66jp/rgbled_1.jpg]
    <td></td>
    <td valign="top">
      <b>向き合わせ</b><br>
      PCBについている三角マークと、LEDの足の角が欠けている方向を一緒にして下さい。<br>
      向きを間違えると他のLEDも含め動作しなくなるので注意して下さい。
    </td>
  </tr>
  <tr>
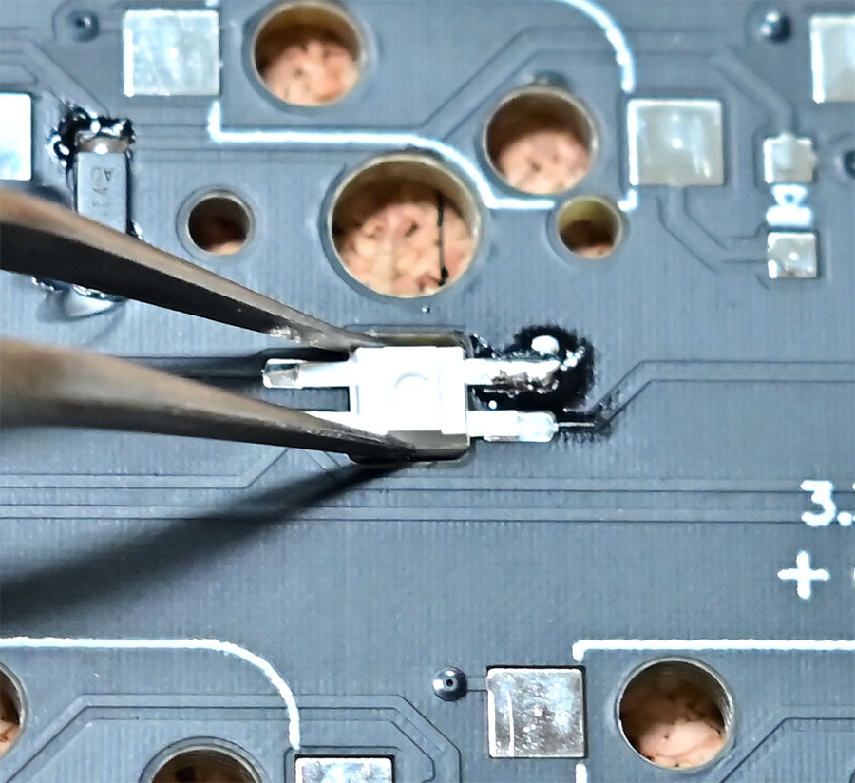
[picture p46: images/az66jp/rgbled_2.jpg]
    <td></td>
    <td valign="top">
      １．　位置合わせ用にピンセット等で押さえながら１か所だけはんだ付けします。
    </td>
  </tr>
  <tr>
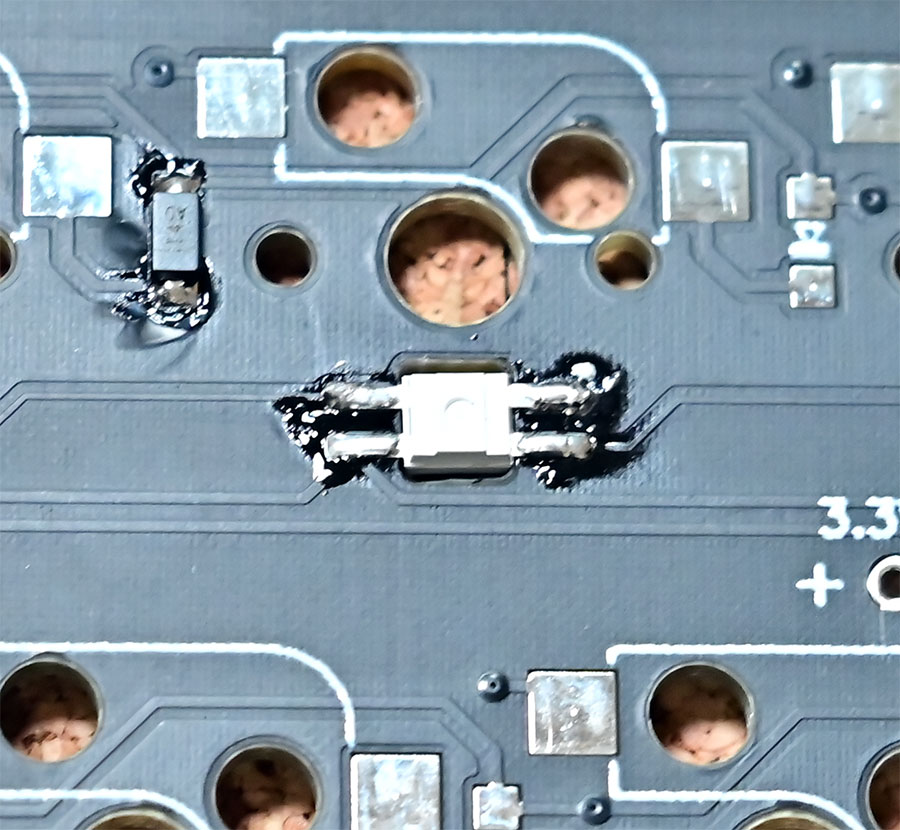
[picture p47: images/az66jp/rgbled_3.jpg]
    <td></td>
    <td valign="top">
      ２．　残り３ヶ所もはんだ付けします。<br>
      １．～２．を66個分繰り返します。
    </td>
  </tr>
</table>

<br><br>

## スイッチ用PCBソケットのはんだ付け
<table>
  <tr>
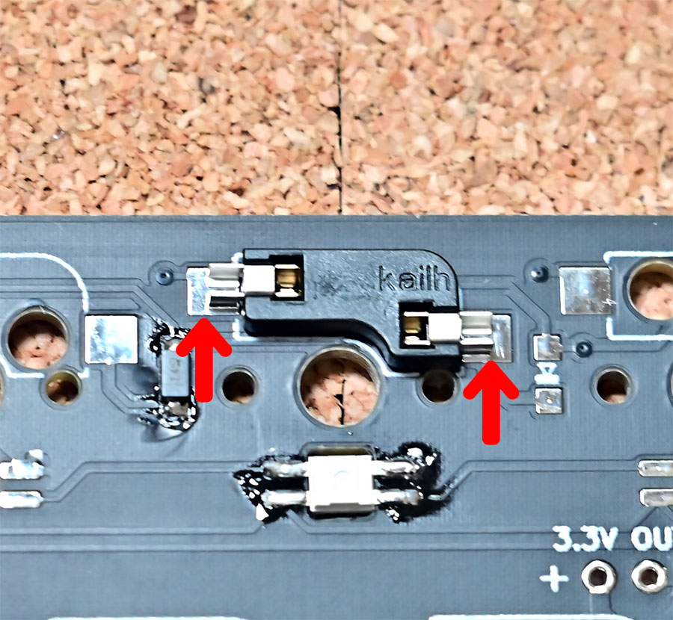
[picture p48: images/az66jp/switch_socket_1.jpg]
    <td><br>
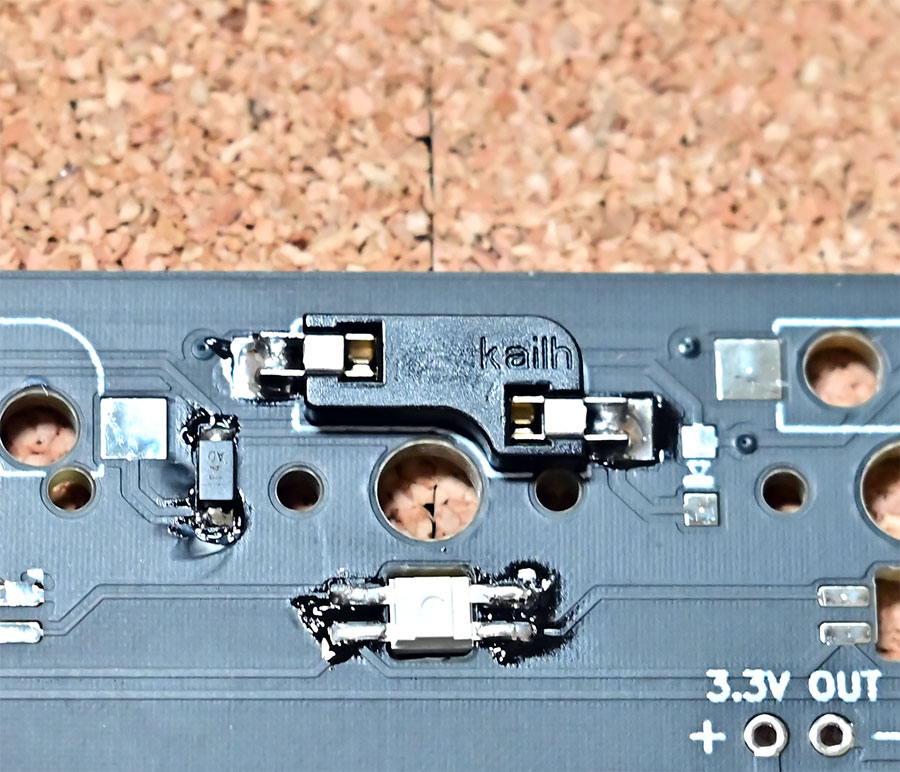
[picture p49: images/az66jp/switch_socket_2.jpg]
    </td>
    <td valign="top">
      ソケット用の穴にソケットを差し込み、矢印部分をはんだ付けします。<br>
      66個分繰り返します。
    </td>
  </tr>
</table>

<br><br>

## USBコネクタのはんだ付け
<table>
  <tr>
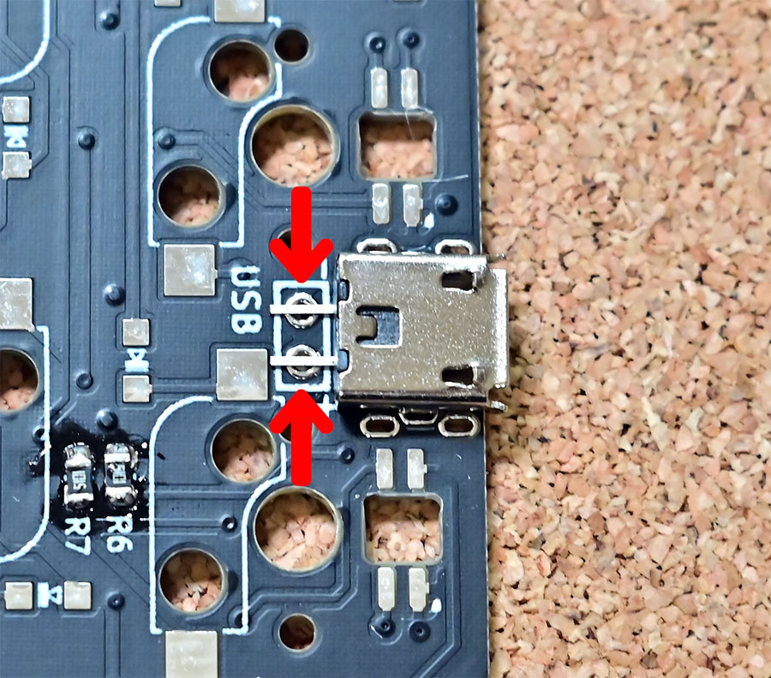
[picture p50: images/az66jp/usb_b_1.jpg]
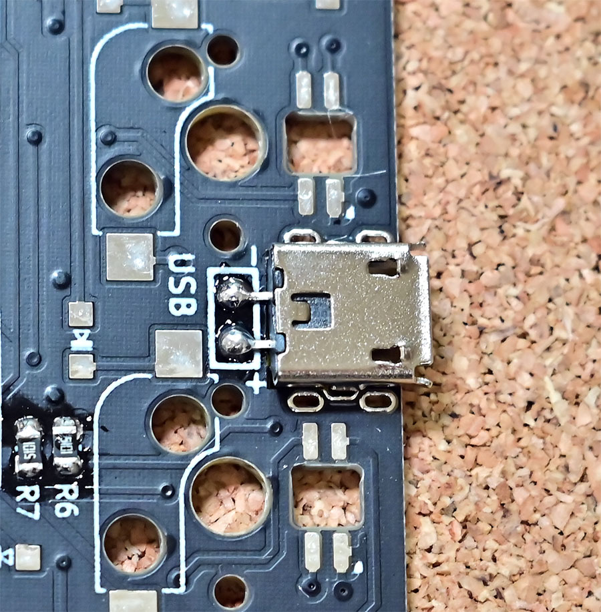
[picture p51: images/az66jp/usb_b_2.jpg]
    <td><br></td>
    <td valign="top">
      PCBの裏側からUSBコネクタを差し込み矢印部分をはんだ付けします。<br>
      足が長くて他の場所と接触してしまいそうな場合は足を少し切って短くしてからはんだ付けして下さい。<br>
    </td>
  </tr>
  <tr>
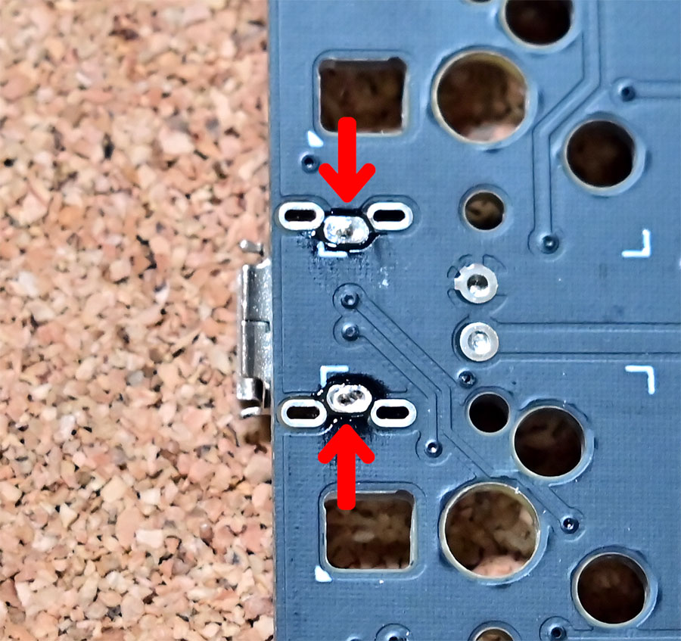
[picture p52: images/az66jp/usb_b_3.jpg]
    <td></td>
    <td valign="top">
      PCBの表側の穴の部分もはんだ付けして下さい。<br>
      表側はトッププレートと接触する部分なのではんだは少な目が良いです。<br>
      <br>
      ※ ここではMicroBコネクタをはんだ付けしましたが、電源コネクタは選べるので好きなコネクタを付けて下さい。<br>
      　　参考 → <a href="/docs/az66jp/power_line/">リンク</a>
    </td>
  </tr>
</table>

<br><br>

## スイッチ接続の動作チェック
<table>
  <tr>
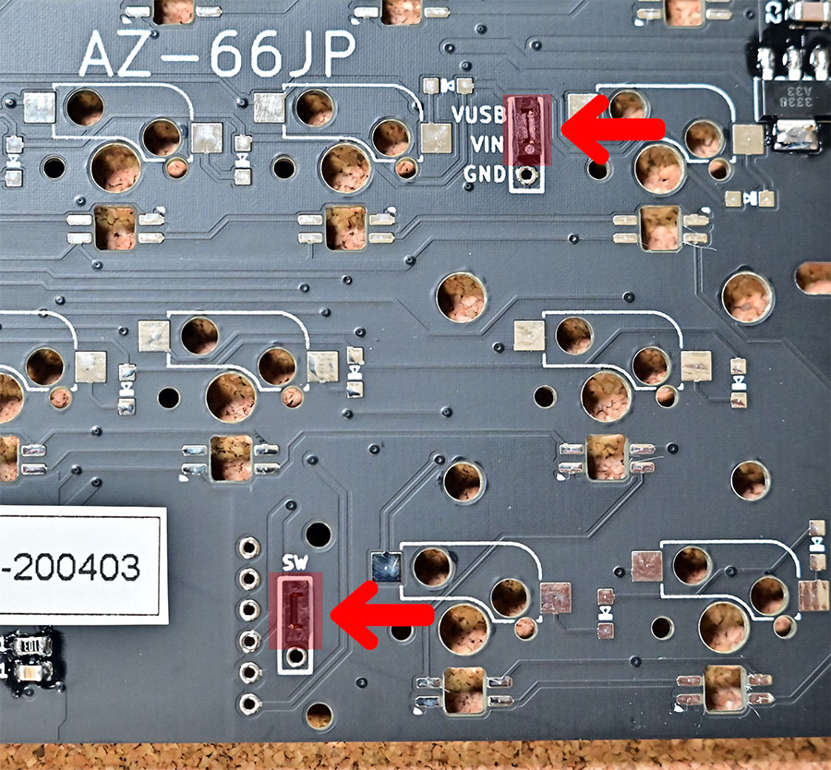
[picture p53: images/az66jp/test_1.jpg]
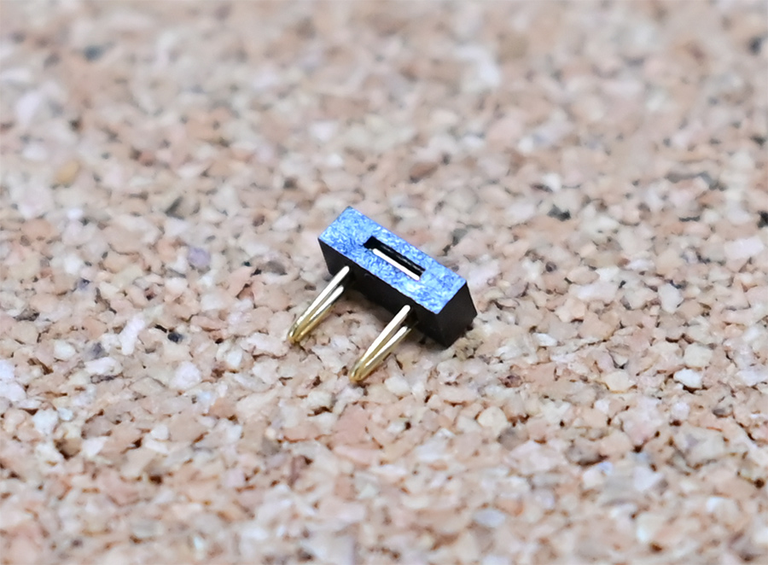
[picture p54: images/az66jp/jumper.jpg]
    <td><br></td>
    <td valign="top">
      66スイッチ全てはんだ付けが終わらない途中の状態でもスイッチの接触確認ができます。<br>
      まずPCB裏面の矢印部分にジャンパーを挿しこんで下さい。<br><br>
      ※ ここで「VUSB」と「VIN」の間に差し込んだジャンパーは完成後も抜かずに挿したままにして下さい。
    </td>
  </tr>
  <tr>
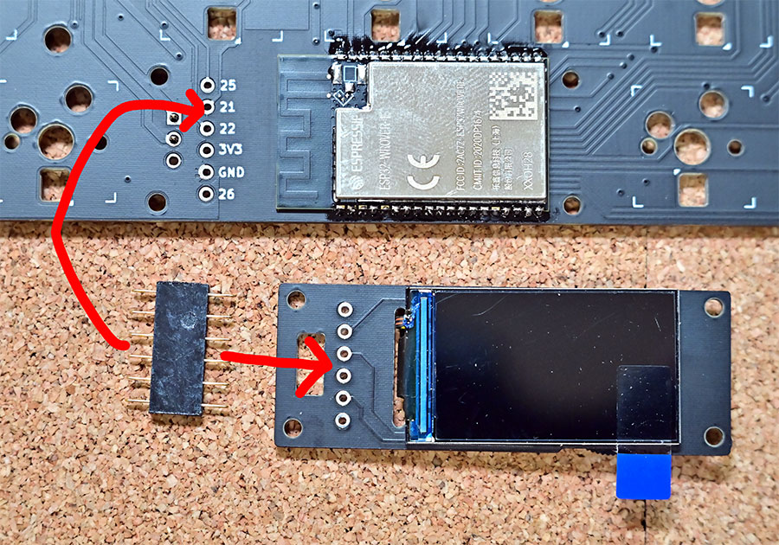
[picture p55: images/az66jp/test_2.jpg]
    <td></td>
    <td valign="top">
      PCBの表側のESP32の隣の穴にコンスル―を差し込んで、その上に液晶プレートを差し込んで下さい。
    </td>
  </tr>
  <tr>
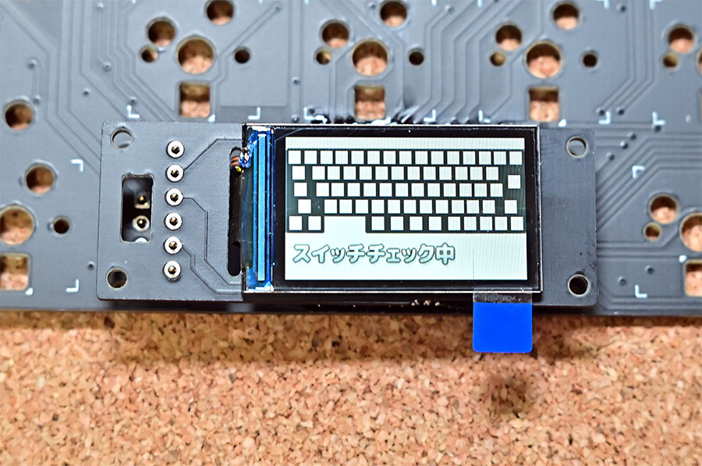
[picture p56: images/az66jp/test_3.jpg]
    <td></td>
    <td valign="top">
      USBコネクタに電源を繋げるとチェックプログラムが起動します。<br>
      この状態ではんだ付けしたソケットにCherryMXスイッチを差し込んで押すと該当箇所が青くなります。
    </td>
  </tr>
</table>

<br><br>

## 電源スイッチのはんだ付け
<table>
  <tr>
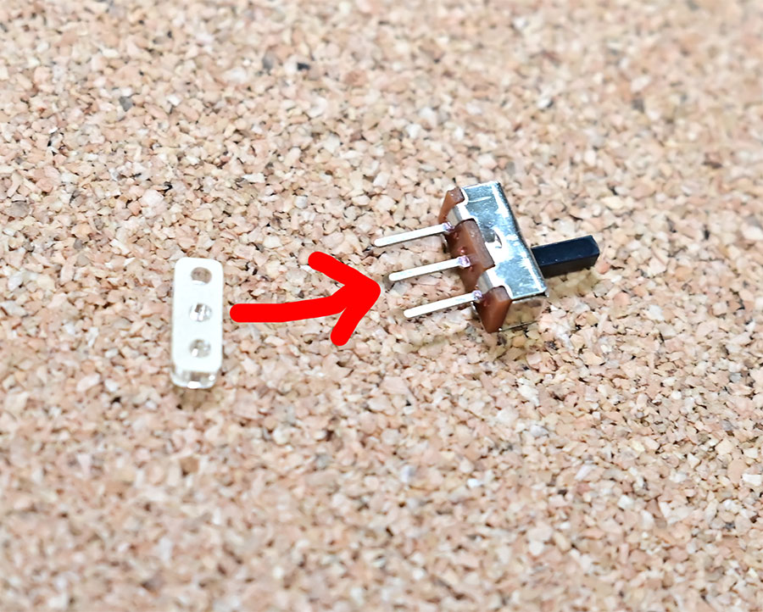
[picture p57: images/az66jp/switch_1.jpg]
    <td></td>
    <td valign="top">
      スイッチをそのままはんだ付けすると高さが足りないので、スイッチの足の下にスペーサーを挟みます。
    </td>
  </tr>
  <tr>
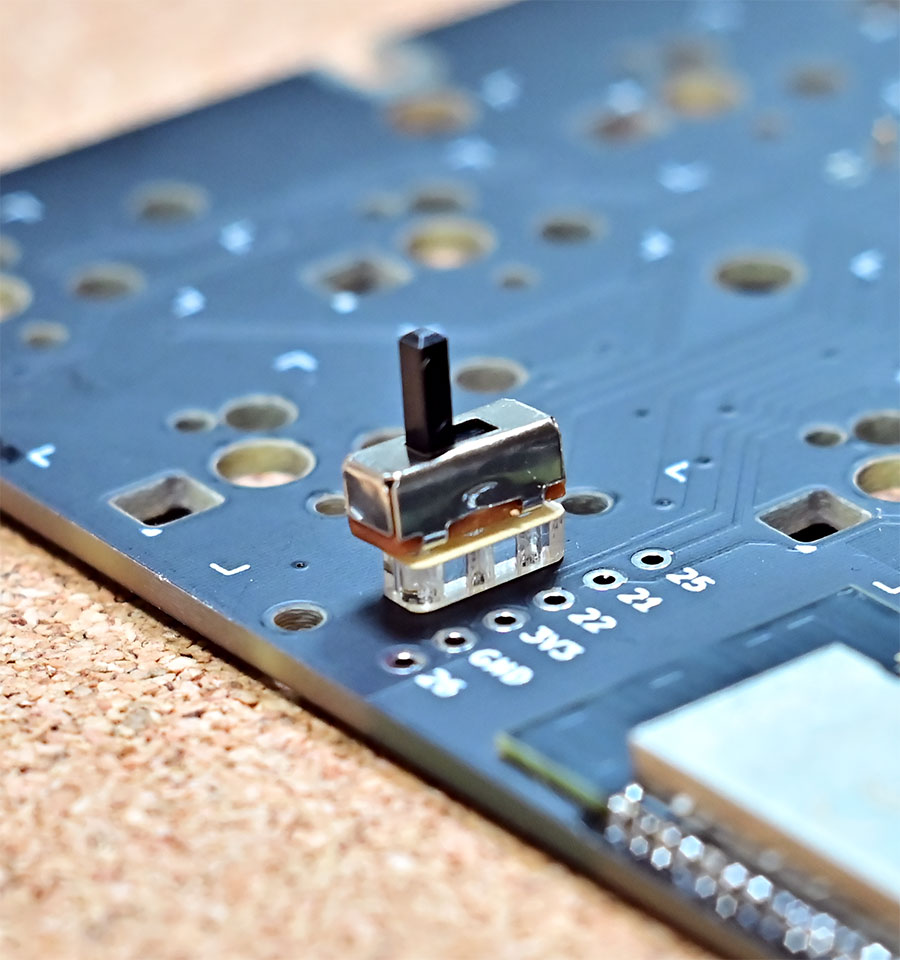
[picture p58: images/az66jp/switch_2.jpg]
    <td></td>
    <td valign="top">
      PCBの表側からスイッチを差し込んで下さい。
    </td>
  </tr>
  <tr>
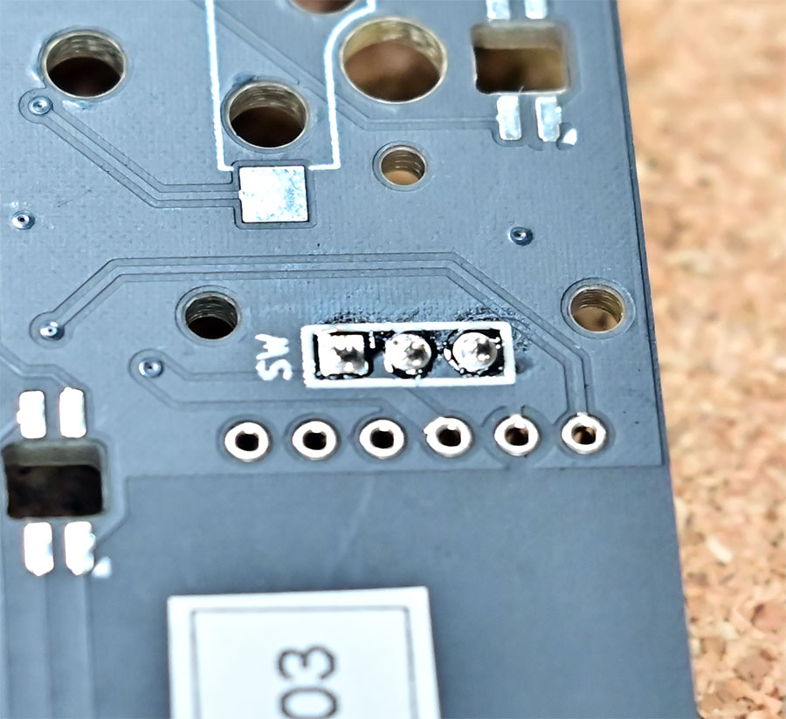
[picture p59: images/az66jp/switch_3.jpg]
    <td></td>
    <td valign="top">
      PCBの裏側からスイッチの足をはんだ付けします。<br>
      この時スイッチが斜めになったりしないよう気を付けて下さい。
    </td>
  </tr>
</table>

<br><br>

## 液晶プレートの固定
<table>
  <tr>
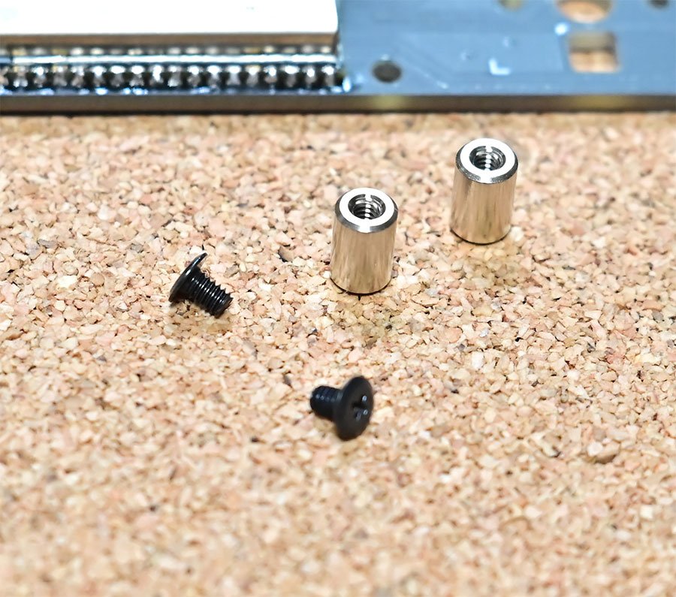
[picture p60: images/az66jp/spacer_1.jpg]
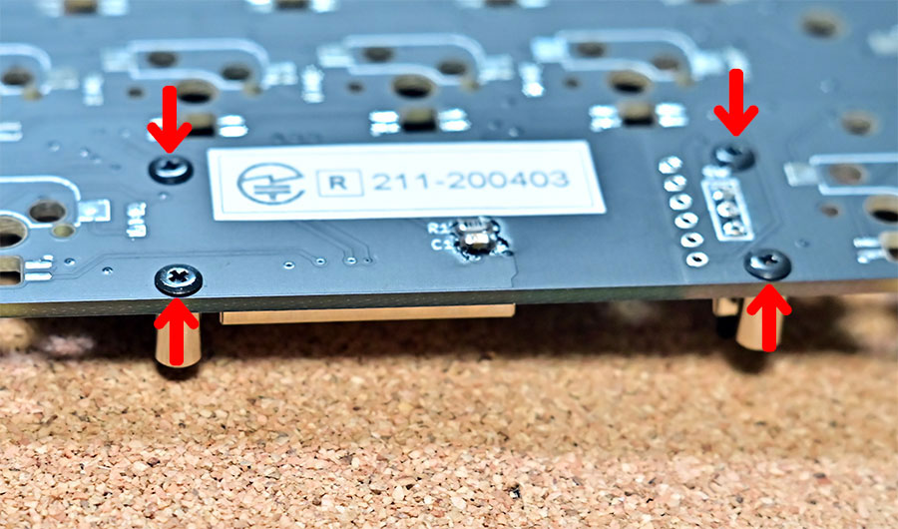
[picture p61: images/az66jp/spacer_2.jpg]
    <td><br></td>
    <td valign="top">
      PCBの裏側から6mmスペーサーと3mmネジを矢印の部分へ止めて下さい。
    </td>
  </tr>
  <tr>
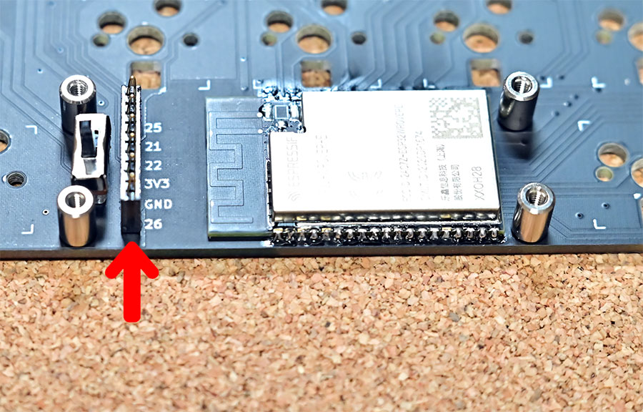
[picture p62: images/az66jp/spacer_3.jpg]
    <td></td>
    <td valign="top">
      PCBを表向きにして矢印部分にコンスル―を差し込んで下さい。
    </td>
  </tr>
  <tr>
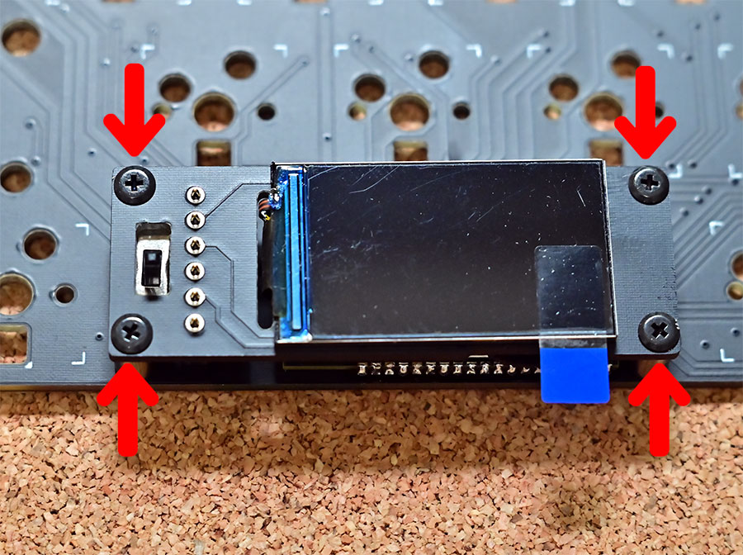
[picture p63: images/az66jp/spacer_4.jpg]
    <td></td>
    <td valign="top">
      その上に液晶プレートを乗せて、矢印部分を3mmネジで止めて下さい。
    </td>
  </tr>
</table>

<br><br>

## スタビライザーの取り付け
<table>
  <tr>
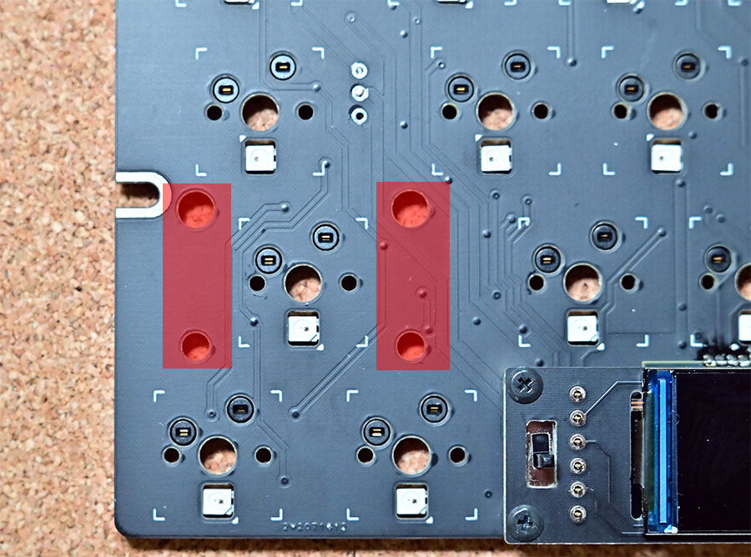
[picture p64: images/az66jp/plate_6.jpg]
    <td></td>
    <td valign="top">
      まずは赤色部分のPCBの表側左下のShiftキー用のスタビライザーを取り付けます。
    </td>
  </tr>
  <tr>
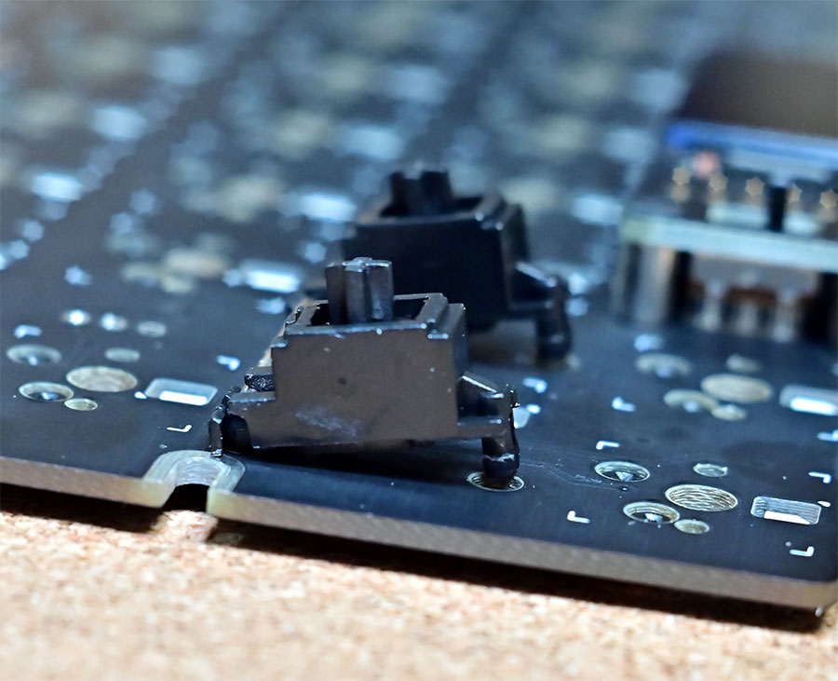
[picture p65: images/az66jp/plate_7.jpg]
    <td></td>
    <td valign="top">
      スタビライザーの繋がっている金具部分を上にして、穴に差し込み引っ掛けます。
    </td>
  </tr>
  <tr>
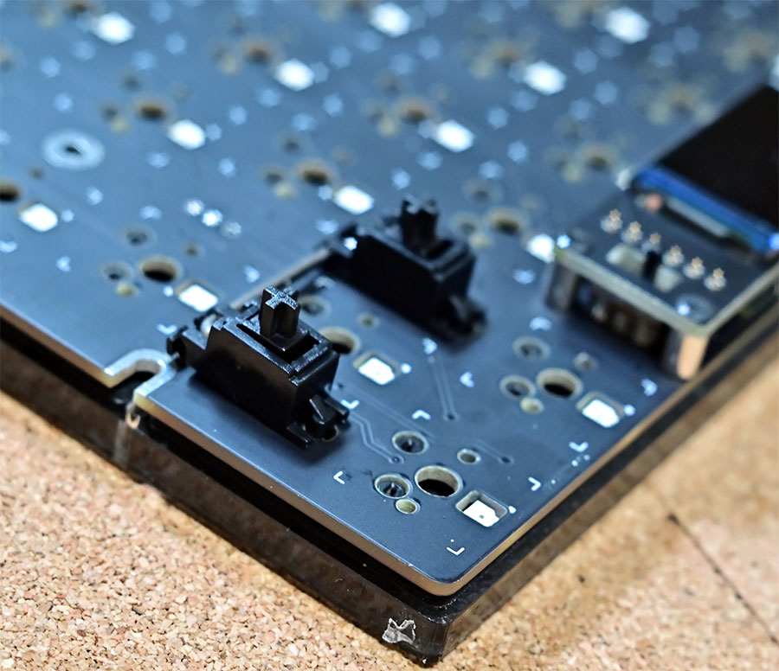
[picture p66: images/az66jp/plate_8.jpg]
    <td></td>
    <td valign="top">
      浮いたもう一個の穴の部分へ押し込むとスタビライザーが取り付けられます。
    </td>
  </tr>
  <tr>
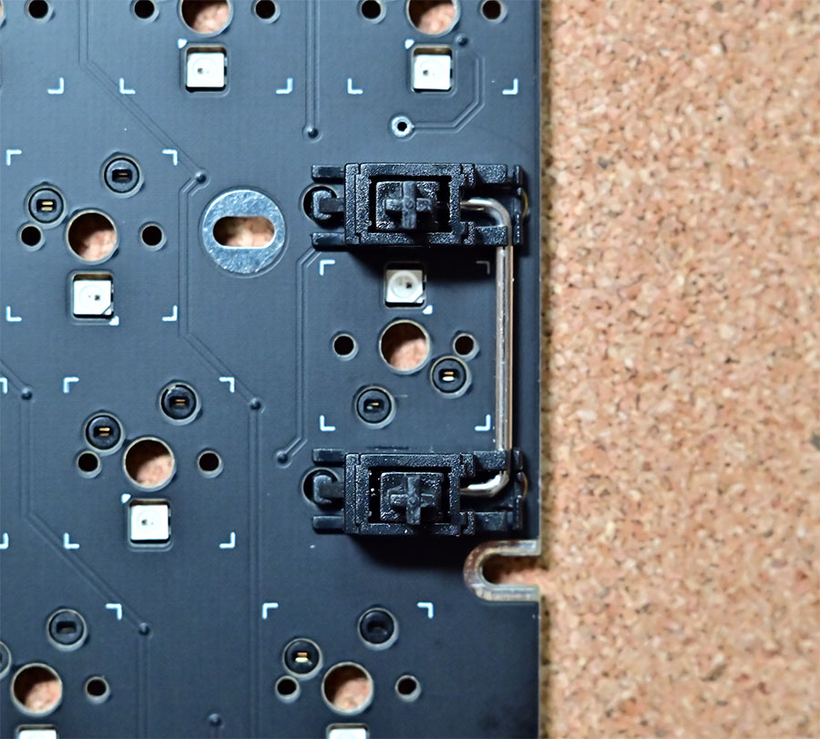
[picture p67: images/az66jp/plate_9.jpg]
    <td></td>
    <td valign="top">
      同じ要領で右側のエンター部分にもスタビライザーを取り付けて下さい。
    </td>
  </tr>
</table>

<br><br>

## ボトムプレートの組み立て
<table>
  <tr>
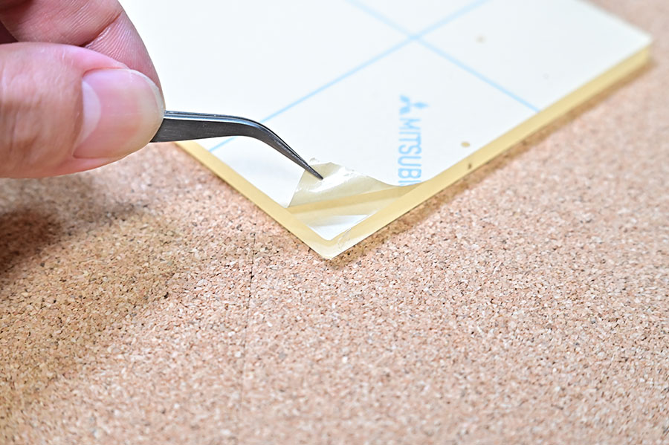
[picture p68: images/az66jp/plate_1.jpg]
    <td></td>
    <td valign="top">
      まずプレートに貼ってある保護シートをピンセットなどを利用してはがして下さい。<br><br>
      　※ バッテリー内蔵プレートを組み立てる場合はこの後の「バッテリー内蔵プレートへのバッテリー貼り付け」を行ってからスポンジの貼り付けをして下さい。
    </td>
  </tr>
  <tr>
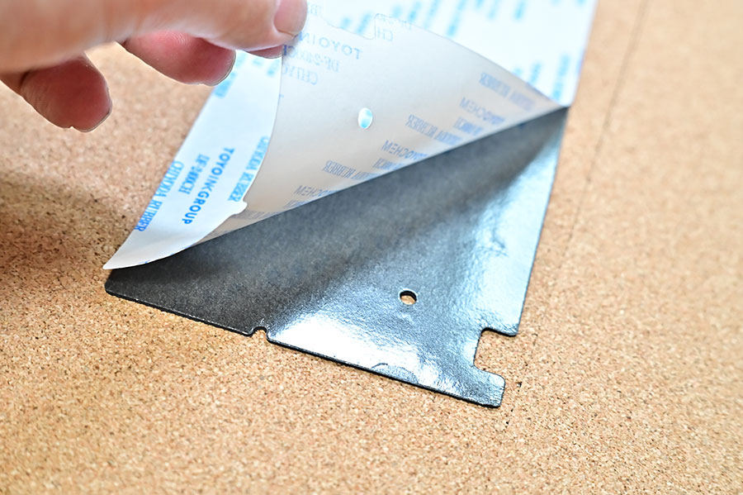
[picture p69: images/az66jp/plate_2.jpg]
    <td></td>
    <td valign="top">
      プレートの表用のスポンジAのテープシートもはがします。<br><br>
      　※ スポンジは1枚のシートになっていますが、切れ目が入っていて簡単に切り離せるので切り離して下さい。<br>
      　※ 見た目を重視するのであればボトムプレートにスポンジを付けずに組み立てると裏面も見れてカッコよくなります。<br>
      　※ スポンジの位置合わせが難しいため心配な方はスポンジを1/2、1/3にカットしてから少しずつ張り付けて下さい。
    </td>
  </tr>
  <tr>
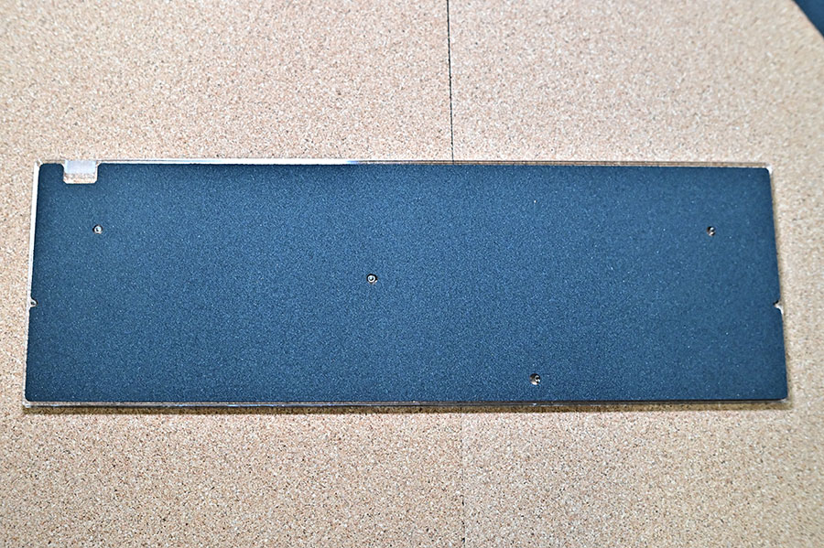
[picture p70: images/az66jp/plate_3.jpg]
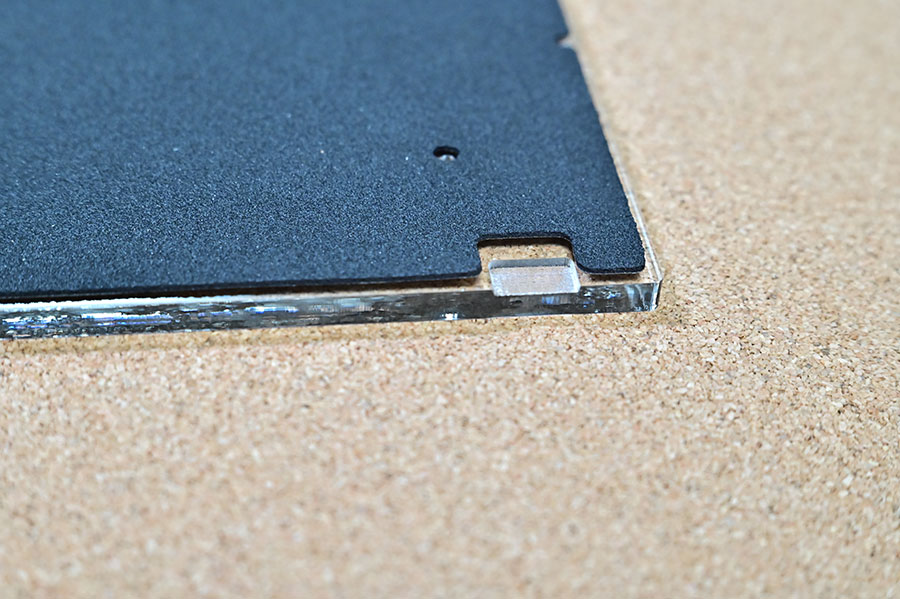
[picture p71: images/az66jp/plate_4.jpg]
    <td><br></td>
    <td valign="top">
      ネジ穴の位置にスポンジの穴が重なるようにスポンジAをボトムプレートの表側に張り付けて下さい。<br><br>
      　※ USBコネクタ用の凹みがある方が表です。
    </td>
  </tr>
  <tr>
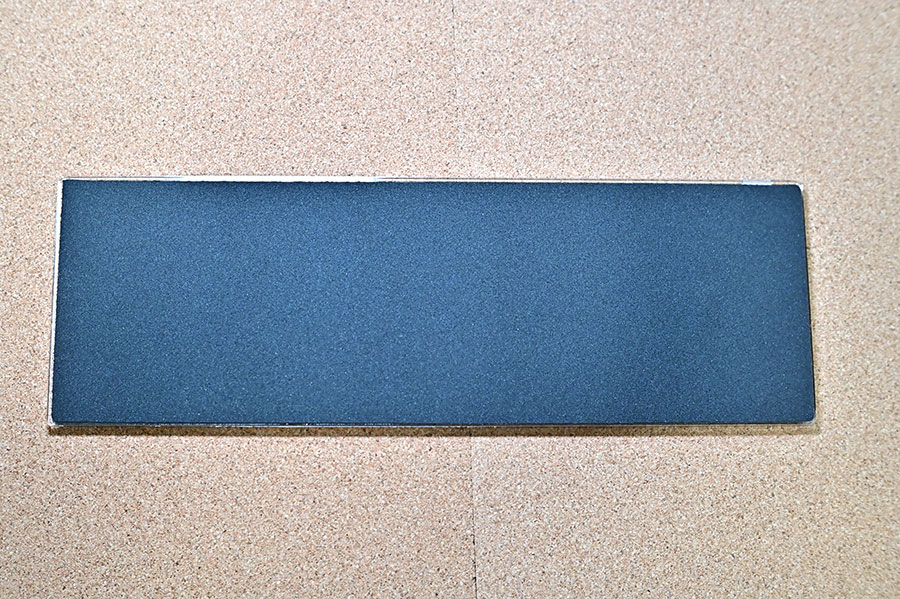
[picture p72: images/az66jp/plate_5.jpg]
    <td></td>
    <td valign="top">
      同じ要領でボトムプレートの裏側にスポンジBを張り付けて下さい。
    </td>
  </tr>
</table>

<br><br>

## バッテリー内蔵プレートへのバッテリー取り付け
<table>
  <tr>
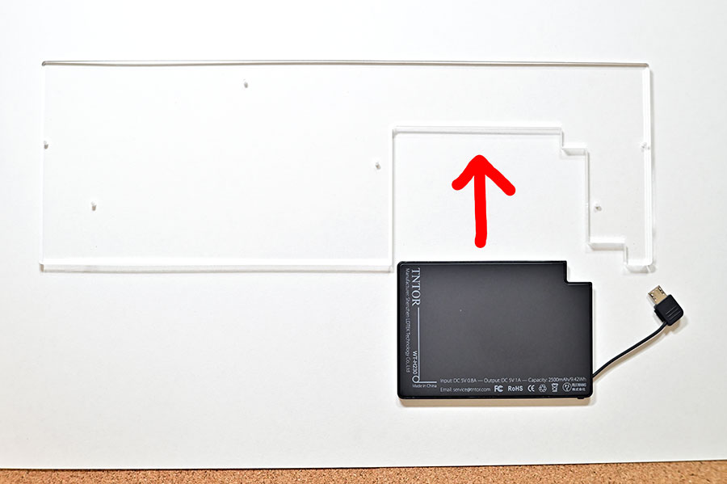
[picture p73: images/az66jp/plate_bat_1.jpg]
    <td></td>
    <td valign="top">
      ボトムプレートの保護シートをはがしたら、写真の方向でモバイルバッテリーを接着します。
    </td>
  </tr>
  <tr>
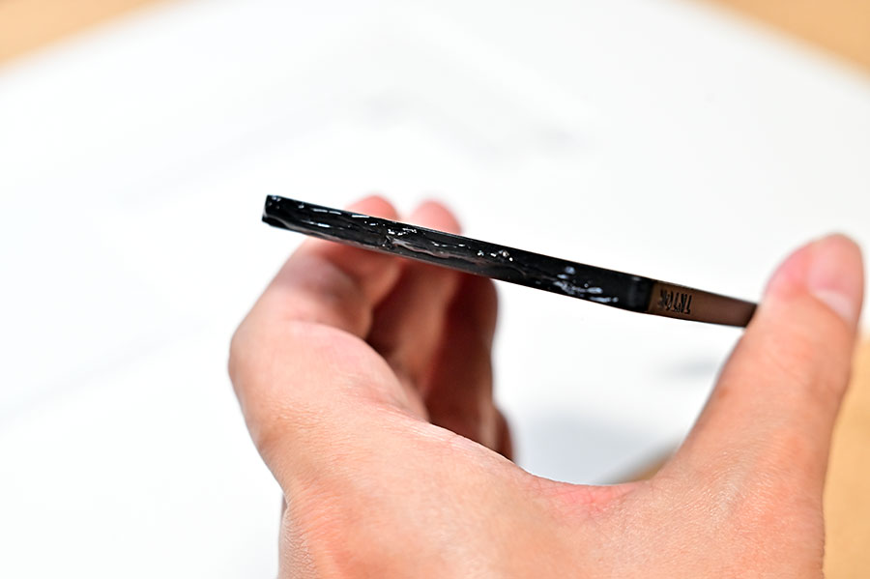
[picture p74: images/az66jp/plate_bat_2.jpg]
    <td></td>
    <td valign="top">
      モバイルバッテリーの側面に瞬間接着剤をぬります。<br><br>
      ※ 他にボンドやテープ類などくっつけば何でも良いです。
    </td>
  </tr>
  <tr>
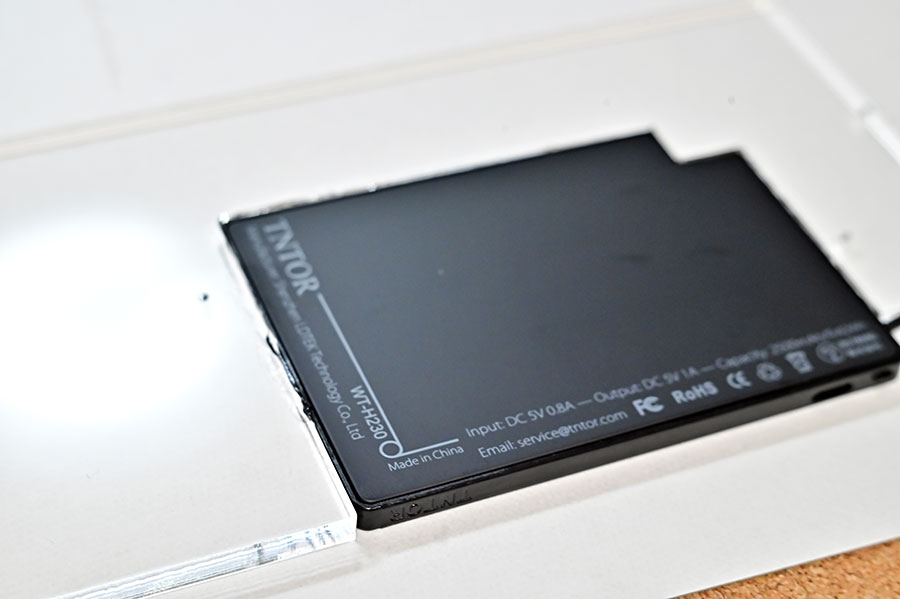
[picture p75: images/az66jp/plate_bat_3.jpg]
    <td></td>
    <td valign="top">
      この時裏側が平らになるように平らな場所に置いて乾かして下さい。<br>乾いたら接着完了です。<br><br>
      ※ 机とのくっつき防止のために画用紙などを敷くと良いです。
    </td>
  </tr>
</table>

<br><br>

## プレートの固定
<table>
  <tr>
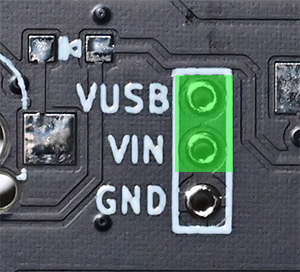
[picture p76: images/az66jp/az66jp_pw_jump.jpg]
    <td></td>
    <td valign="top">
      PCBプレートの裏側の電源ラインを付属しているジャンパーで「VUSB」と「VIN」ショートして繋げて下さい。
    </td>
  </tr>
  <tr>
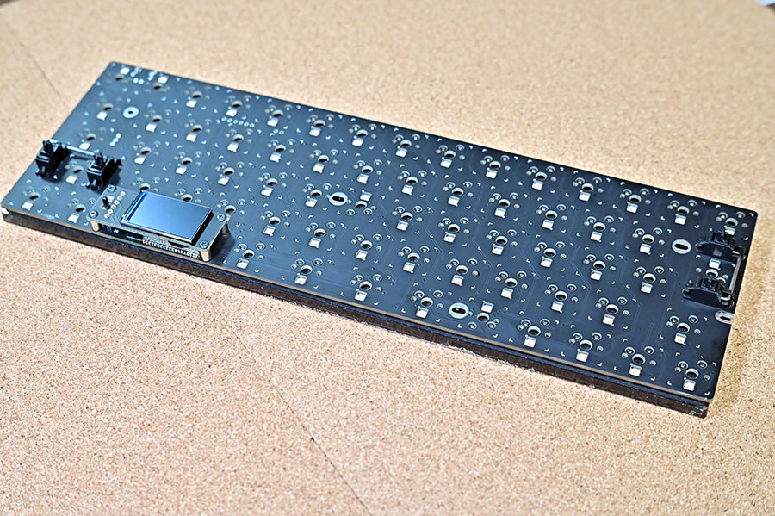
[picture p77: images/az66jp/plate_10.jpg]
    <td></td>
    <td valign="top">
      ボトムプレートの上にPCBプレートを乗せます。
    </td>
  </tr>
  <tr>
    <td></td>
    <td valign="top">
      その上にトッププレートを乗せます。
    </td>
  </tr>
  <tr>
    <td><br></td>
    <td valign="top">
      矢印の部分を14mmネジでとめて下さい。<br>
      この時のネジの締め具合で打鍵音が変わります。ゆるい方が静かで、固く締めるほどボトムプレートに振動が伝わりカチャカチャ音がします。<br>
      オススメはトッププレートを押すとトッププレートが沈むくらいゆるく止めた方が打鍵音が良いです。
    </td>
  </tr>
</table>

<br><br>

プレートの固定まで終われば組み立て完了です。<br>
後はキースイッチを差し込んで、キーキャップを取り付けて下さい。<br>
スイッチを差し込んでいる時も電源を入れるとスイッチの接触確認ができて便利です。<br>

<br>



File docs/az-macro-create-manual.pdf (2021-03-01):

－ 作成 マニュアル －

2

## ファームウェアの初期セットアップ

まず最初はファームウェアの初期セットアップが必要です。

github にファームウェアの初期セットアップマニュアルがございますので、まずはこちらの URL を参考に

ファームウェアの初期セットアップを行って下さい。

ファームウェアの初期セットアップマニュアル

https://github.com/palette-system/az-macro/tree/master/docs/firmware_write


3

## 入っている物

１ | PCB プレート × １ | ７ | M2 １２ｍｍ ネジ × ２
２ | ミドルプレート × ４ | ８ | M2 ５ｍｍ スペーサー × ３
３ | 耐熱シート × １ | ９ | M2 １０ｍｍ ネジ × １
４ | ボトムプレート × １ | １０ | 保護プレート × １
５ | M2 ナット × １０ | １１ | ゴム足 × ４
６ | M2 ２０ｍｍ ネジ × ２


4

## 別途必要な物

１ | LiPo バッテリー × １ | ３ | キーキャップ × ８
２ | キースイッチ × ８

※ キースイッチは Cherry MX、Kailh ロープロファイルの２種類対応しています。

※ 必ずリチウムイオンポリマー1 セル、400mAh 以上、保護回路付きの物をご利用下さい。

※ バッテリーは PH-2P のプラグが付いている物にして下さい。

■動作確認済みのバッテリー

https://www.sengoku.co.jp/mod/sgk_cart/detail.php?code=EEHD-4YZL

https://www.sengoku.co.jp/mod/sgk_cart/detail.php?code=EEHD-4YZM

https://www.sengoku.co.jp/mod/sgk_cart/detail.php?code=EEHD-4YZN


5

## 作り始める前に動作確認

はんだ付けをした後に動作不良があった場合、はんだ付けの問題なのか初期不良なのかの切り分けが出来

ず、交換が受け付けれなくなってしまいます。

はんだ付け前に動作不良があれば初期不良として交換を受け付けれますので、必ず作成前に動作確認を行

って下さい。

## 動作確認手順


１．まずバッテリーの PH プラグを出っ張りがある方を上にして PCB ボードへ接続して下さい。

プラグは硬めなので強く差し込んで下さい。写真の所まで差し込めたら OK です。

２．バッテリーが接続できると表面にあるスイッチを下に下げれば電源が入ります。

電源が入ると緑色の電源 LED が点灯します。


6

３．電源が入ると PC やスマートフォンから Bluetooth キーボードとして認識できます。

キーボード名「az-macro」で PC やスマートフォンから検索して接続して下さい。

４．接続ができたらキーボードとして動いているハズなので、キースイッチの代わりにピンセットを

使用して、写真の所のスイッチ穴に触れてみて下さい。

８個のボタンの金属部分に触れて、PC やスマートフォンに a～h の文字が入力されれば動作確認完了

です。

５．動作確認が完了したら電源スイッチを上(OFF)にして、バッテリーを外してください。

バッテリーが外れにくい場合はラジオペンチなどを使用して外してください。

## キースイッチのはんだ付け


7

１．はんだ付けできればどんな方法でも大丈夫なのですが、ここでは手間の少ない方法を紹介します。

まずは PCB プレートを表向きにして、スイッチを乗せます。

２．スイッチの上にボトムプレートを乗せます。横から見るとこんな感じです。

３．スイッチが抜けないよう抑えながら持ち上げ、そのまま裏返します。

この時全てのキーがちゃんと奥まで刺さっていて PCB プレートが水平になっていれば OK です。


8

４．キースイッチの接続部分をはんだ付けします。

写真のようにはんだ付けが終わった後、出っ張っている部分を必ずニッパーでカットして下さい。

※そのままにしているとバッテリーに刺さる可能性があります。

→

## 組み立て

１．保護プレートに付いている保護シートをピンセットなどではがします。


9

２．保護プレートの外側のネジ穴２つに２０ｍｍのネジを差し込み、スペーサーを差し込みます。

保護プレートは表裏があり、上下も微妙に違うので気を付けて下さい。


10

３．さらに PCB プレートを裏向きで差し込み、ナットで固定します。


11

４．保護プレートにあるもう１つのネジ穴は１０ｍｍのネジで同じくスペーサーを挟んでナットで固定し

ます。

５．PCB ボードの反対側のネジ穴は１２ｍｍネジを差し込んでナットで固定します。


12

６．バッテリー用 PH ソケットが穴に入る向きにして、耐熱シートをネジ穴に通して下さい。

７．ミドルプレート１枚ずつネジ穴に通して下さい。

サイズをピッタリにし過ぎてしまったので、ネジに引っかかります。強めに押し込んでください。

８．PH ソケットにバッテリーを接続して、ミドルプレート内にコードが収まるように収納して下さい。


13

９．ボトムプレートを差し込み、ナットで固定して下さい。

１０．ゴム足を付けて下さい。


14

１１．キーキャップを付けて完成です。

キーキャップは強く押し込むと付きます。

完 成 ！

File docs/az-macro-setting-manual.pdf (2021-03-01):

－ 設定 マニュアル －

2

## ファームウェアの初期セットアップ

組み立てキットご購入の方も、完成品ご購入の方も、まず最初はファームウェアの初期セットアップが必

要です。

github にファームウェアの初期セットアップマニュアルがございますので、まずはこちらの URL を参考に

ファームウェアの初期セットアップを行って下さい。

ファームウェアの初期セットアップマニュアル

https://github.com/palette-system/az-macro/tree/master/docs/firmware_write


3

## 設定モードで起動する

キー０を押したまま電源を入れると緑色の LED がゆっくりと点滅し、設定モードで起動します。この間

キーボードとしては動作しません。

設定モード中は WIFI のアクセスポイントとなっていて、スマートフォンや PC から「AZ-Macro-****」へ

WIFI アクセスすると設定画面を開く事ができます。

WIFI 接続すると自動的に設定画面が開きますが、端末によってはログインページを開くボタンが表示さ

れるので、ログインページを開いて下さい。

iOS などではセキュリティのため自動で開かれないので、その場合は WIFI 接続後ブラウザから

「http://192.168.4.1」へアクセスして下さい。


4

## メイン画面

１．現在編集しているキーボードの種類が表示されます。

２．設定メニューを開きます。詳細については設定メニューの説明に記述します。

３．現在選択しているレイヤーが表示されます。

４．現在キーに割り当てている設定が表示されます。キーをタップするとキーの設定ができます。

５．インフォメーションテキストが表示されます。

６．変更したキー設定を AZ-Macro に保存して設定モードを終了します。

７．変更を保存せずに設定モードを終了します。

5

## キー設定画面

メイン画面に表示されているキーをタップすると、キーの設定画面に移動します。


キー番号：現在編集しているキーの番号

動作：キーを押した時の動作

・動作無し

キーを押しても何も起こりません

・通常キー入力

Ctrl＋C など指定したキーの入力

・テキスト入力

パスワードなど登録したテキストの入力

・レイヤー切り替え

キーを押している間別のレイヤーの動作になりま

す。

・WEB フック

設定した URL を開き内容をキー入力します

・マウス移動

押している間マウスカーソルを移動します

決定：キーの設定を反映しメイン画面に戻ります。

キャンセル：何もせずにメイン画面に戻ります。

6


通常キー入力 キー１～５： 入力するキーを設定できます。 変更： 設定したキーを変更できます。 ×： ２つ目以降のキーは削除できます。 入力キー追加： 同時に押すキーを追加できます。 最大５キーまで同時入力できます。


### テキスト入力 テキスト： 入力させたいテキストを登録できます。 半角英数字、記号のみで全角文字は登録で きません。


### レイヤー切り替え レイヤー： 切り替えるレイヤーを設定できます。

7


### WEB フック

URL：

開くページの URL を設定できます。

デフォルトでパレットシステムのカウント

アップ URL が指定されます。

HTTP ヘッダー：

HTTP リクエストヘッダーを追加する事が

できます。複数指定できます。

編集(HTTP ヘッダー)：

登録してあるヘッダーを編集できます。

削除(HTTP ヘッダー)：

登録してあるヘッダーを削除できます。

HTTP ヘッダー追加：

ヘッダーを新しく追加できます。

POST データ：

POST で任意のデータを送信できます。

キーバリュー、JSON など自分でフォーマ

ットして指定して下さい。

この欄を空にすると GET リクエストにな

ります。

キー操作：

HTTP 取得した後のキー動作を下記から指

定できます。

・動作無し

・ステータスコードを入力

・HTTP レスポンスを入力

※ WIFI 設定がしてある必要があります。

※ HTTP レスポンスは 1024 バイトまで取得し

ます。

※ HTTP レスポンス内に全角文字が含まれてい

ると入力動作が不安定になります。

8


### HTTP ヘッダー

Key：

ヘッダーのキーを指定します。

Value：

ヘッダーのバリューを指定します。

決定：

変更を反映して WEB フック設定画面に戻

ります。

キャンセル：

変更を反映せずに WEB フック設定画面に

戻ります。


### マウス移動

X：

X 座標の移動を設定します。

マイナスで左、プラスで右に動きます。

Y：

Y 座標の移動を設定します。

マイナスで上、プラスで下に動きます。

スピード：

０～100 で移動速度を設定します。

０を指定するとキーを押した際に１回だけ

設定した X,Y ピクセル分カーソルが移動し

ます。

9

## レイヤー機能

レイヤー機能を使用すると「キー０を押したままキー１を押した時」のような２キー以上の同時押し動作

を設定する事ができます。

レイヤー０がデフォルトとなっていて、メイン画面のレイヤー枠の「＋」をタップするとレイヤーが追加

できます。

「×」をタップすると現在選択しているレイヤーを削除します。レイヤー０はデフォルトのため削除でき

ません。

「▼」をタップすると選択しているレイヤーを変更できます。

レイヤーごとにキー設定が可能で、キーに対して「レイヤー切り替え」の動作を設定するとそのキーが押

されている間は指定したレイヤーのキー動作に切り替わります。

また AZ-Macro 起動時にキーの下の段「４，５，６，７」のキーを押したまま AZ-Macro の電源を入れる

とそれぞれ別のレイヤーがデフォルトとして起動します。使用するアプリケーションによってキーを切り

替えたい時にご利用ください。

押すキー番号 | デフォルトになるレイヤー番号
４ | １
５ | ２
６ | ３
７ | ４

10

## 設定メニュー


### 日本語/US 切り替え：

日本語キーボード、US キーボードの選択

ができます。

### キーボードの種類：

使用しているキーボードを変更できま

す。

### スイッチ接触確認：

キーが押されているかどうかの動作確認

ができます。

### WIFI 設定：

キーボードが WIFI にアクセスするための

ssid とパスワードを設定できます。

### ログイン設定：

設定画面の WIFI にアクセスするためのパ

スワードを設定できます。

### 設定の初期化：

キーボードに設定した内容を購入時の状

態に戻します。

### ファームウェア：

ファームウェアバージョンの確認とアッ

プデートが行えます。

11

## 設定メニュー 各説明


日本語/US 切り替え 変更： キーボードの言語を変更できます。 iOS 等で使用する場合は US キーボードを 選択してください。 決定： 変更を決定してメニューに戻ります。 キャンセル： 変更せずにメニューに戻ります。

キーボードの種類設定 変更： キーボードの種類を変更できます。 オプションを付けた場合に変更してくださ い。 決定： 変更を決定して本体を再起動します。 キャンセル： 変更せずにメニューに戻ります。

12


### スイッチ接触確認

この画面が表示されている間本体のキーを押す

と押されたボタンの部分が緑色になります。

半田付けのチェック用に使用してください。

完了：

メニューに戻ります。

WIFI 設定 一覧

キーボード本体が WIFI に接続するための設定が

できます。設定は複数設定可能で、一番電波が

強いアクセスポイントに接続しに行きます。

この設定をするとキーボードモードで起動した

時に WIFI に接続しに行くので起動が遅くなりま

す。また、WIFI に常時接続した状態なので電池

の消費が早いです。WEB フックなどを使用する

予定が無い場合は設定しない事をオススメしま

す。

編集：

登録した WIFI 設定を編集します。

削除：

登録した WIFI 設定を削除します。

WIFI 追加：

新しく WIFI 設定を登録します。

完了：

メニューに戻ります。

13


WIFI 設定 編集

ssid：

登録するアクセスポイントの SSID を入力し

ます。

「▼」を押すと現在接続できるアクセスポ

イントのリストが表示されます。

pass：

アクセスポイントに接続するためのパスワ

ードを入力します。

決定：

変更を決定して WIFI 一覧に戻ります。

キャンセル：

変更をせずに WIFI 一覧に戻ります。


### ログイン設定

pass：

設定画面に入るための WIFI パスワードを設

定します。

ここで指定したパスワードを忘れると設定

画面に入れなくなるので必ずパスワードを

メモして下さい。

決定：

変更を決定してメニューに戻ります。

キャンセル：

変更を反映せずにメニューに戻ります。

14


### 設定の初期化

全ての設定を出荷時の状態に戻します。

初期化する：

設定を出荷時の状態に戻し、再起動しま

す。

キャンセル：

初期化せずにメニューに戻ります。

### ファームウェア

バージョン：

現在のファームウェアバージョンが表示さ

れます。

ファイル：

配布された bin ファイルを選択します。

スマートフォンの場合、端末により参照を

タップしてもファイルが選択できない場合

があるので PC での作業をオススメしま

す。

アップデート：

ファイルで指定したファームウェアにアッ

プデートします。

アップデート中は緑色の LED が点滅し続け

ますので、点滅が終わるまで本体の電源を

落とさないで下さい。

キャンセル：

ファームウェアを更新せずにメニューに戻

ります。

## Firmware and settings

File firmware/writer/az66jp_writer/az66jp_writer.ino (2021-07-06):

#include "Arduino.h"
#include <WiFi.h>
#include <WiFiClient.h>
#include <WebServer.h>
#include <Update.h>
#include <ESPmDNS.h>
#include <DNSServer.h>
#include <Adafruit_NeoPixel.h>


#include "src/lib/Arduino_ST7789_my.h"
#include "src/image/az_66jp_img.h"
#include "index_bin.h"
#include "image.h"



// 液晶 オブジェクト
Arduino_ST7789 *tft; // st7789オブジェクト

// RGBLED
#define RGBLED_LENGTH   70
#define RGBLED_PIN   14
Adafruit_NeoPixel *rgb_led; // RGB_LEDオブジェクト
int rgbled_index;
int rgbled_step;

// キー用IOピン
#define  ROW_LENGTH   5
#define  COL_LENGTH   14
#define  KEY_LENGTH   70
int row_pin[] = {35, 34, 39, 36, 23};
int col_pin[] = {1, 3, 19, 18, 5, 4, 0, 2, 15, 32, 33, 27, 12, 13};


// サーモ表示用のボタンの位置
const uint8_t az66jp_key_position[70][2] PROGMEM = {
  {4, 4}, {8, 19}, {10, 35}, {14, 51}, {5, 67}, {20, 4}, {28, 19}, {32, 35}, {40, 51}, {24, 67},
  {36, 4}, {43, 19}, {47, 35}, {55, 51}, {0, 0}, {51, 4}, {59, 19}, {63, 35}, {71, 51}, {0, 0},
  {67, 4}, {75, 19}, {79, 35}, {87, 51}, {87, 67}, {83, 4}, {91, 19}, {95, 35}, {103, 51}, {106, 67},
  {99, 4}, {107, 19}, {111, 35}, {119, 51}, {125, 67}, {115, 4}, {123, 19}, {127, 35}, {135, 51}, {0, 0},
  {131, 4}, {139, 19}, {143, 35}, {151, 51}, {144, 67}, {147, 4}, {155, 19}, {159, 35}, {167, 51}, {163, 67},
  {163, 4}, {171, 19}, {175, 35}, {182, 51}, {179, 67}, {179, 4}, {186, 19}, {190, 35}, {198, 51}, {195, 67},
  {195, 4}, {202, 19}, {206, 35}, {0, 0}, {210, 67}, {210, 4}, {226, 4}, {224, 27}, {220, 51}, {226, 67}
};

// 既に押したことがあるボタンかどうか
uint8_t  key_oncheck[KEY_LENGTH];

// 無線LANのサーバー設定
const byte DNS_PORT = 53;
DNSServer dnsServer;
WebServer server(80);


// IP アドレスデータを表示用の文字列にする
String toStringIp(IPAddress ip) {
    String res = "";
    for (int i = 0; i < 3; i++) {
        res += String((ip >> (8 * i)) & 0xFF) + ".";
    }
    res += String(((ip >> 8 * 3)) & 0xFF);
    return res;
}

//無効リクエストはすべてESP32に向ける
void captivePortal() {
    server.sendHeader("Location", "http://"+toStringIp(WiFi.softAPIP())+"/", true);
    server.send(302, "text/plain", "");
    server.client().stop();
}


// wifi 初期処理
void start_wifi() {
    int i, j;
    char text_buf[255];
    
    //無線LAN接続AP(アクセスポイント)モード
    WiFi.mode(WIFI_AP_STA);
    WiFi.softAP("az-66jp", "");

    // DNSサーバー起動
    IPAddress myIP = WiFi.softAPIP();
    dnsServer.start(DNS_PORT, "*", myIP); // 全ドメインを自分に向ける
    ESP_LOGD(LOG_TAG, "server ip : %S", toStringIp(myIP));

    // メインページ
    server.on("/", []() {
        server.send(200, "text/html", index_bin);
    });
    // OTA 用updater
    server.on("/firmware_update", HTTP_POST, []() {
        server.sendHeader("Connection", "close");
        server.send(200, "text/plain", (Update.hasError()) ? "FAIL" : "OK");
        delay(2000);
        ESP.restart();
    }, []() {
        // ファイルを受け取ってファームウェアを更新
        HTTPUpload& upload = server.upload();
        if (upload.status == UPLOAD_FILE_START) {
            ESP_LOGD(LOG_TAG, "Update: file start %s\n", upload.filename.c_str());
            if (!Update.begin(UPDATE_SIZE_UNKNOWN)) { //start with max available size
                // Update.printError(Serial);
            }
            tft->fillRect(0, 92,  240, 43, WHITE);
            tft->viewBMP(6, 100, 190, 26, (uint8_t *)firm_write_now_txt_img, 10); // ファームウェア書込み中
            
        } else if (upload.status == UPLOAD_FILE_WRITE) {
            /* flashing firmware to ESP*/
            ESP_LOGD(LOG_TAG, "Update: write %D\n", upload.currentSize);
            if (Update.write(upload.buf, upload.currentSize) != upload.currentSize) {
                // Update.printError(Serial);
            }
        } else if (upload.status == UPLOAD_FILE_END) {
            ESP_LOGD(LOG_TAG, "Update: end\n");
            if (Update.end(true)) { //true to set the size to the current progress
                ESP_LOGD(LOG_TAG, "Update Success: %u\nRebooting...\n", upload.totalSize);
            } else {
                // Update.printError(Serial);
            }
        }
    });
    // httpサーバーそれ以外のページ
    server.onNotFound([]() {
        ESP_LOGD(LOG_TAG, "onNotFound: %S", server.uri().c_str());
        // メインページにリダイレクト
        server.sendHeader("Location", "http://"+toStringIp(WiFi.softAPIP())+"/", true);
        server.send(302, "text/plain", "");
        server.client().stop();
    });
    // httpサーバー起動
    server.begin();
}

// RGBLED用のループ
void led_loop() {
    int i;
    rgbled_step++;
    if (rgbled_step < 5) return;
    rgbled_step = 0;
    rgbled_index++;
    if (rgbled_index > 66) return;
    for (i=0; i<RGBLED_LENGTH; i++) {
        if (i < rgbled_index) {
            rgb_led->setPixelColor(i, rgb_led->Color(0, 0, 1));
        } else {
            rgb_led->setPixelColor(i, rgb_led->Color(0, 0, 0));
        }
    }
    rgb_led->show();
}

// キー入力をスキャンして液晶に表示
void key_scan() {
    int i, j, s, n;
    n = 0;
    // マトリックス入力の取得
    for (i=0; i<COL_LENGTH; i++) {
        // 対象のcolピンのみ lowにする
        for (j=0; j<COL_LENGTH; j++) {
            if (i == j) { s = 0; } else { s = 1; }
            digitalWrite(col_pin[j], s);
        }
        delayMicroseconds(50);
        // row の分キー入力チェック
        for (j=0; j<ROW_LENGTH; j++) {
            if (!az66jp_key_position[n][0]) {
                n++;
                continue;
            }
            if (!digitalRead(row_pin[j])) {
                tft->fillRect(az66jp_key_position[n][0] - 1, az66jp_key_position[n][1] + 9,  12, 12, BLUE);
                key_oncheck[n] = 1;
            } else if (key_oncheck[n]) {
                tft->fillRect(az66jp_key_position[n][0] - 1, az66jp_key_position[n][1] + 9,  12, 12, 0x667f);
            } else {
                tft->fillRect(az66jp_key_position[n][0] - 1, az66jp_key_position[n][1] + 9,  12, 12, WHITE);
            }
            n++;
        }
    }
}



void setup() {
    int i;
    // 液晶初期化
    tft = new Arduino_ST7789(26, 25, 21, 22, -1);
    tft->init(240, 135);
    tft->setRotation(1);
    delay(100);
    tft->fillRect(0, 0,  240, 10, WHITE);
    tft->fillRect(0, 92,  240, 43, WHITE);
    tft->viewBMP(0, 10, 240, 82, (uint8_t *)az_66jp_plate_img, 10);
    tft->viewBMP(6, 100, 166, 26, (uint8_t *)switch_chack_now_txt_img, 10); // スイッチチェック中
    // RBGLED初期化
    rgbled_index = 0;
    rgbled_step = 0;
    rgb_led = new Adafruit_NeoPixel(RGBLED_LENGTH, RGBLED_PIN, NEO_GRB + NEO_KHZ400);
    for (i=0; i<RGBLED_LENGTH; i++) {
        rgb_led->setPixelColor(i, rgb_led->Color(0, 0, 0));
    }
    rgb_led->show();
    // キー用初期化
    for (i=0; i<COL_LENGTH; i++) {
        pinMode(col_pin[i], OUTPUT_OPEN_DRAIN);
    }
    for (i=0; i<ROW_LENGTH; i++) {
        pinMode(row_pin[i], INPUT_PULLUP);
    }
    for (i=0; i<KEY_LENGTH; i++) {
        key_oncheck[i] = 0;
    }
    // 設定モード開始
    start_wifi();
}


// ループ処理本体
void loop() {
    // dnsサーバー定期処理
    dnsServer.processNextRequest();
    // httpサーバー定期処理
    server.handleClient();
    // キー入力をスキャンして液晶に表示
    key_scan();
    // RGBLEDチェック用
    led_loop();
    delay(50);
}

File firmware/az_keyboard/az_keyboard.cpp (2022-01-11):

#include "Arduino.h"
#include "az_keyboard.h"
#include "az_common.h"
#include "src/lib/ble_keyboard_jis.h"
#include "src/lib/custom_func.h"
#include "src/lib/ankey.h"
#include "src/lib/dakey.h"
#include "src/lib/paw3204.h"

// BLEキーボードクラス
BleKeyboardJIS bleKeyboard(BLUETOOTH_SEARCH_NAME);

// 拡張関数クラス
CustomFunc my_function = CustomFunc();

// トラックボールクラス
Paw3204 pawTrackball = Paw3204();

// 暗記ボタンクラス
Ankey ankeycls = Ankey();

// 打鍵カウントクラス
Dakey dakeycls = Dakey();


// コンストラクタ
AzKeyboard::AzKeyboard() {
}

// キーボードとして処理開始
void AzKeyboard::start_keyboard() {
    // ステータスLED wifi接続中
    status_led_mode = 4;

    // メモリ空けるためファイルシステム終了
    // SPIFFS.end();

    // EEPROMも終了
    EEPROM.end();

    // Wifi 接続
    ESP_LOGD(LOG_TAG, "mmm: %D %D\n", heap_caps_get_free_size(MALLOC_CAP_32BIT), heap_caps_get_free_size(MALLOC_CAP_8BIT) );
    common_cls.wifi_connect();
    ESP_LOGD(LOG_TAG, "mmm: %D %D\n", heap_caps_get_free_size(MALLOC_CAP_32BIT), heap_caps_get_free_size(MALLOC_CAP_8BIT) );
    
    // bluetoothキーボード開始
    ESP_LOGD(LOG_TAG, "mmm: %D %D\n", heap_caps_get_free_size(MALLOC_CAP_32BIT), heap_caps_get_free_size(MALLOC_CAP_8BIT) );
    bleKeyboard.begin();
    ESP_LOGD(LOG_TAG, "mmm: %D %D\n", heap_caps_get_free_size(MALLOC_CAP_32BIT), heap_caps_get_free_size(MALLOC_CAP_8BIT) );
    
    // キーボードの言語を指定(日本語=0/ US=1 / 日本語(US記号) = 2)
    bleKeyboard.set_keyboard_language(keyboard_language);

    // ステータスLED点灯
    status_led_mode = 1;

    // キーの入力状態初期化
    common_cls.key_read();
    common_cls.key_old_copy();

    // マウス移動リスト初期化
    press_mouse_list_clean();

    // バッテリーレベル
    // bleKeyboard.setBatteryLevel(100);

    // 暗記ボタン初期化
    ankeycls.begin(this);

    // 打鍵クラス初期化
    dakeycls.begin();

    // 各ユニット初期化
    start_unit();

    press_key_all_clear = -1;

    // 拡張関数 開始処理
    my_function.begin();

    // 液晶は待ち受け画像
    if (common_cls.on_tft_unit()) disp->view_type = DISP_TYPE_STANDBY;
  
}

// 各ユニットの初期化
void AzKeyboard::start_unit() {
    if (option_type_int == 2) {
        // トラックボール
        pawTrackball.begin(27, 12);
    }
}

// 前回のキーのステータスと比較して変更があった物だけ処理を実行する
void AzKeyboard::key_action_exec() {
    if (remap_input_test) {
      // Serial.printf("remap_input_test: %d\n", remap_input_test);
      remap_input_test--;
      return;
    }
    // 暗記データのキー入力中は何もしない
    if (ankeycls.ankey_flag == 2) return;
    // キー入力チェック
    int i;
    for (i=0; i<key_input_length; i++) {
        if (common_cls.input_key_last[i] != common_cls.input_key[i]) {
            if (common_cls.input_key[i]) {
                // キーが押された
                key_down_action(i); // 押された時の動作
                rgb_led_cls.set_led_buf(i, 1); // LED に押したよを送る
                ankeycls.key_down(i); // 暗記クラスに押したよを送る(暗記用)
                // 打鍵数カウントアップ
                common_cls.key_count[i]++;
                common_cls.key_count_total++;
            } else {
                // キーは離された
                key_up_action(i); // 離された時の動作
                rgb_led_cls.set_led_buf(i, 0); // LED に離したよを送る
                ankeycls.key_up(i); // 暗記クラスに離したよを送る(暗記用)
            }
        }
    }
}

// キー連打処理
void AzKeyboard::key_repeat_exec() {
    int i, k;
    for (i=0; i<PRESS_KEY_MAX; i++) {
        if (press_key_list[i].key_num < 0) continue;
        if (press_key_list[i].action_type == 1 && 
            press_key_list[i].repeat_interval >= 0 &&
            press_key_list[i].repeat_interval <= 50) { // 通常キー入力で連打設定がある
            if (press_key_list[i].repeat_index >= press_key_list[i].repeat_interval) {
                k = press_key_list[i].key_id;
                if (k & MOUSE_CODE) {
                    // マウスボタンだった場合
                    bleKeyboard.mouse_press(k - MOUSE_CODE); // マウスボタンを押す
                    delay(10);
                } else {
                    // キーコードだった場合
                    bleKeyboard.press_raw(k); // キーを押す
                    delay(10);
                }
                press_key_list[i].repeat_index = 0;
            }
            if (press_key_list[i].repeat_index == 0) {
                // 押してスグキーを離す
                if (k & MOUSE_CODE) {
                    // マウスボタンだった場合
                    bleKeyboard.mouse_release(k - MOUSE_CODE); // マウスボタンを離す
                } else {
                    // キーコードだった場合
                    bleKeyboard.release_raw(k); // キーを離す
                }
            }
            press_key_list[i].repeat_index++;
        }
    }
}
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

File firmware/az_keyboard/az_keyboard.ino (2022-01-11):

#include "az_common.h"
#include "az_keyboard.h"
#include "az_setting.h"


// 起動モード
int boot_type;

// 共通クラス
AzCommon common_cls = AzCommon();

// キーボードモードクラス
AzKeyboard azkb = AzKeyboard();

// 設定モードクラス
AzSetting azstg = AzSetting();

void setup() {
    int i, j, s;
    // 共通処理の初期化
    common_cls.common_start();
    // 設定jsonの読み込み
    common_cls.load_setting_json();
    // ステータス表示用のLED初期化
    if (status_pin >= 0 && option_type_int != 3) {
        pinMode(status_pin, OUTPUT);
        digitalWrite(status_pin, 0);
        status_led_mode = 0;
        common_cls.set_status_led_timer();
    }
    // ディスプレイ初期化
    if (common_cls.on_tft_unit()) {
        disp = new Display();
        disp->begin(tft, option_type_int);
    }
    // RGB_LEDクラス初期化
    ESP_LOGD(LOG_TAG, "rgb_led_cls.begin %D %D %D", rgb_pin, matrix_row, matrix_col);
    if (rgb_pin > 0 && matrix_row > 0 && matrix_col > 0) {
        rgb_led_cls.begin( rgb_pin, matrix_row, matrix_col, &select_layer_no, led_num, key_matrix, AZ_NEO_KHZ);
    }
    // キーの入力ピンの初期化
    common_cls.pin_setup();
    // 起動回数を読み込み
    common_cls.load_boot_count();
    // 打鍵数を自動保存するかどうかの設定を読み込み
    key_count_auto_save = 0;
    common_cls.load_file_data(KEY_COUNT_AUTO_SAVE_PATH, (uint8_t *)&key_count_auto_save, 1);
    // eepromからデータ読み込み
    common_cls.load_data();
    ESP_LOGD(LOG_TAG, "boot_mode = %D\r\n", eep_data.boot_mode);
    boot_type = eep_data.boot_mode;
    // 0番目のキーが押されていたら設定モードにする
    common_cls.key_read(); // キーの状態を取得
    if (common_cls.input_key[SETTING_MODE_KEY] || common_cls.input_key[44]) boot_type = 1;
    // 0番目と3番目と4番目のキーが押されていて、1番目と2番目は離されていたら初期化（１，２が離されているのを確認する事で上に物が乗ってて全押しされて誤って初期化されないようにしている）
    if (common_cls.input_key[0] && !common_cls.input_key[1] && !common_cls.input_key[2] && common_cls.input_key[3] && common_cls.input_key[4]) {
        // 全てのファイルを削除
        common_cls.delete_all();
        // ディスプレイに初期化完了の表示
        if (common_cls.on_tft_unit()) {
            disp->view_setting_init_comp();
        }
        // キーが離されたら終了して再起動
        while (true) {
            common_cls.key_read(); // キーの状態を取得
            // 0～4全てのキーが離されたら終了
            if (!common_cls.input_key[0] && !common_cls.input_key[1] && !common_cls.input_key[2] && !common_cls.input_key[3] && !common_cls.input_key[4]) break;
            delay(50);
        }
        // 画面を真っ暗にする
        if (common_cls.on_tft_unit()) {
            disp->view_full_black();
        }
        // キーボードモードに切り替え
        common_cls.change_mode(0);
        return;
    }
    // 4～5番目のキーが押されていたらデフォルトレイヤーを切り替える
    common_cls.set_default_layer_no();
    if (boot_type == 1) {
        ESP_LOGD(LOG_TAG, "設定モード起動\n");
        // 設定モード開始
        azstg.start_setting();
        // 次回起動時キーボード起動するようモード設定
        common_cls.set_boot_mode(0);

    } else {
        ESP_LOGD(LOG_TAG, "キーボードモード起動\n");
        if (common_cls.on_tft_unit() && op_movie_flag) {
            disp->open_movie();
        }
        // キーボードとして起動
        azkb.start_keyboard();
    }
}


// ループ処理本体
void loop() {
    if (boot_type == 1) {
      // 設定モード用ループ
      azstg.loop_exec();

    } else {
      // キーボードモード用ループ
      azkb.loop_exec();
    }
}

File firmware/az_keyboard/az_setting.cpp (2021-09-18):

#include "Arduino.h"
#include <WiFi.h>
#include <WiFiClient.h>
#include <WebServer.h>
#include <Update.h>
#include <ESPmDNS.h>
#include <DNSServer.h>
#include "az_common.h"
#include "az_setting.h"

#include "src/html/index_bin.h"
#include "src/html/config_js_bin.h"
#include "src/html/index_js_bin.h"



//無線LANのサーバー設定
const byte DNS_PORT = 53;
DNSServer dnsServer;
WebServer server(80);

// ファイルアップロードの戻り値用
char upload_buf[64];

// ファイルアップロードのステータス
int upload_stat;

// ファイルアップ用のファイルポインタ
File upfp;

// キーが押されたか
int last_key_down = -1;

// IP アドレスデータを表示用の文字列にする
String toStringIp(IPAddress ip) {
    String res = "";
    for (int i = 0; i < 3; i++) {
        res += String((ip >> (8 * i)) & 0xFF) + ".";
    }
    res += String(((ip >> 8 * 3)) & 0xFF);
    return res;
}

// wifiアクセスポイントのリストをJSONで取得
String get_wifi_ap_list_json(){
    ESP_LOGD(LOG_TAG, "get_wifi_ap_list: start");
    String res = "{\"list\": [";
    int ssid_num;
    String auth_open;
    ssid_num = WiFi.scanNetworks();
    if (ssid_num == 0) {
        ESP_LOGD(LOG_TAG, "get_wifi_ap_list: no networks");
    } else {
        ESP_LOGD(LOG_TAG, "get_wifi_ap_list: %d\r\n", ssid_num);
        for (int i = 0; i < ssid_num; ++i) {
            auth_open = ((WiFi.encryptionType(i) == WIFI_AUTH_OPEN)? "true": "false");
            if (i > 0) res += ",";
            res += "{\"ssid\": \"" + WiFi.SSID(i) + "\", \"rssi\": \"" + WiFi.RSSI(i) + "\", \"auth_open\": " + auth_open + "}";
            delay(10);
        }
    }
    res += "]}";
    ESP_LOGD(LOG_TAG, "%S", res);
    return res;
}


void captivePortal() {
    //無効リクエストはすべてESP32に向ける
    server.sendHeader("Location", "http://"+toStringIp(WiFi.softAPIP())+"/", true);
    server.send(302, "text/plain", "");
    server.client().stop();
}

bool handleUrl(String path) {
    char scmd[64];
    int i, n, r;
    path.toCharArray(scmd, 64);
    ESP_LOGD(LOG_TAG, "url path: %S", scmd);
    if (path.equals("/")){
        // メインページ
        server.send(200,"text/html", index_html_bin);
        return true;

    } else if (path.indexOf("/index.js") == 0) {
        // メインjs
        server.send(200,"text/js", index_min_js_bin);
        return true;

    } else if (path.indexOf("/config.js") == 0) {
        // メインjs
        server.send(200,"text/js", config_js_bin);
        return true;

    } else if (path.indexOf("/firmware_version") == 0) {
        // ファームウェアのバージョン教えて
        sprintf(scmd, "{\"v\": \"%S\", \"t\": %D}", FIRMWARE_VERSION, AZESP32_TYPE);
        server.send(200,"text/html", scmd);
        return true;

    } else if (path.indexOf("/last_key_down") == 0) {
        // 最後に押されたキー教えて(キーの現在の設定も返す)
        sprintf(scmd, "%D", last_key_down);
        server.send(200,"text/plan", scmd);
        last_key_down = -1;
        return true;

    } else if (path.indexOf("/get_key_status") == 0) {
        // 現在のキーの入力状態を教えて
        for (i=0; i<key_input_length; i++) {
            if (common_cls.input_key[i]) {
                scmd[i] = '1';
            } else {
                scmd[i] = '0';
            }
        }
        scmd[i] = '\0';
        server.send(200,"text/plan", scmd);
        return true;

    } else if (path.indexOf("/key_length") == 0) {
        // キーの数教えて
        sprintf(scmd, "%D", key_input_length);
        server.send(200,"text/plan", scmd);
        return true;

    } else if (path.indexOf("/get_setting_json") == 0) {
        // 設定JSON教えて
        File json_file = SPIFFS.open(SETTING_JSON_PATH);
        server.streamFile(json_file, "text/json");
        json_file.close();
        return true;

    } else if (path.indexOf("/file_list") == 0) {
        // ファイルリストの取得
        File dirp = SPIFFS.open("/");
        File filep = dirp.openNextFile();
        String res = "{\"data\": [";
        while(filep){
            res += "\"" + String(filep.name()) + "\",";
            filep = dirp.openNextFile();
        }
        res += "\".\"]}";
        server.send(200,"text/plan", res.c_str());

    } else if (path.indexOf("/read_file_") == 0) {
        // 指定したファイルを読み込み ( /read_file_{ファイル名} でアクセス)
        // パスの後ろがファイル名
        String file_path = "/" + path.substring(11);
        // 読み込んで返す
        if(SPIFFS.exists(file_path)){
            File fp = SPIFFS.open(file_path, "r");
            server.streamFile(fp, "application/octet-stream");
            fp.close();
        } else {
            server.send(500,"text/plan", "file none");
        }
        return true;
        
    } else if (path.indexOf("/delete_file_") == 0) {
        // 指定されたファイルを削除( /delete_file?{ファイル名} でアクセス)
        // パスの後ろがファイル名
        String file_path = "/" + path.substring(13);
        // 削除処理
        if(SPIFFS.exists(file_path)){
            if (!SPIFFS.remove(file_path)) {
                server.send(500,"text/plan", "file delete error");
                return true;
            }
        }
        server.send(200,"text/plan", "OK");
        return true;
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

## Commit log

2021-01-15 add WEBHook sample
2021-02-21 基本操作マニュアル追加
2021-02-22 add plate license
    [az-macro-bottom.dxf, az-macro-middle.dxf, az-macro-protection.dxf]
2021-02-22 edit plate
    [az-macro-bottom.dxf, az-macro-middle.dxf]
2021-04-28 add led and tft
2021-05-12 add ankey led
2021-05-15 add led setting
2021-05-22 track readme
2021-05-24 led reset
2021-06-10 add 16mb setting
    [large_spiffs12MB_16MB.csv]
2021-06-14 add led type and ankey disp
2021-06-22 heatmap change
2021-06-30 add power readme
2021-06-30 edit power
2021-06-30 edit power readme
2021-07-12 add track speed
2021-07-13 add esp32 img
2021-07-13 add color led
2021-07-15 add led doc

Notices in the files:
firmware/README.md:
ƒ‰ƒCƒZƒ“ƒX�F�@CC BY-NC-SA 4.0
